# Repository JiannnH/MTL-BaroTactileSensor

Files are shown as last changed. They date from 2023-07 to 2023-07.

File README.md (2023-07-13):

# MTL-BaroTactileSensor

This repository contains the code and hardware design for the research project titled "Superresolution of a Barometric Tactile Sensor." The project is being conducted as part of an MSc Thesis at Imperial College London, which is continually updating.

# Project Description
The objective of this project is to develop an integrated tactile sensor solution based on traditional barometers to produce a more precise and sophisticated tactile output. The project encompasses the entire development cycle, including PCB design, hardware design, data collection, and deep learning model training.

The primary focus of the project is on enhancing the resolution of tactile sensors using machine learning techniques.

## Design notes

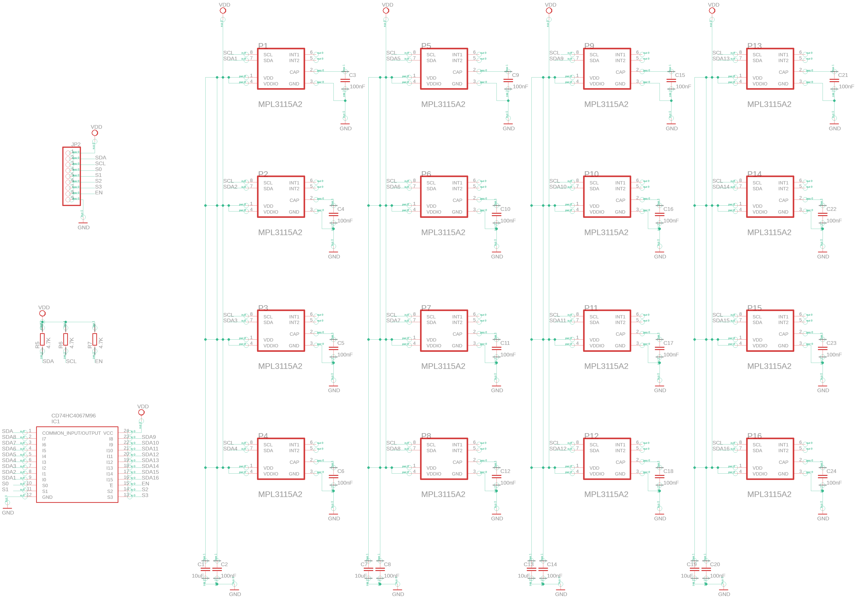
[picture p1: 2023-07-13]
PCB/BarometerMTL_V3.1/Schematic.png

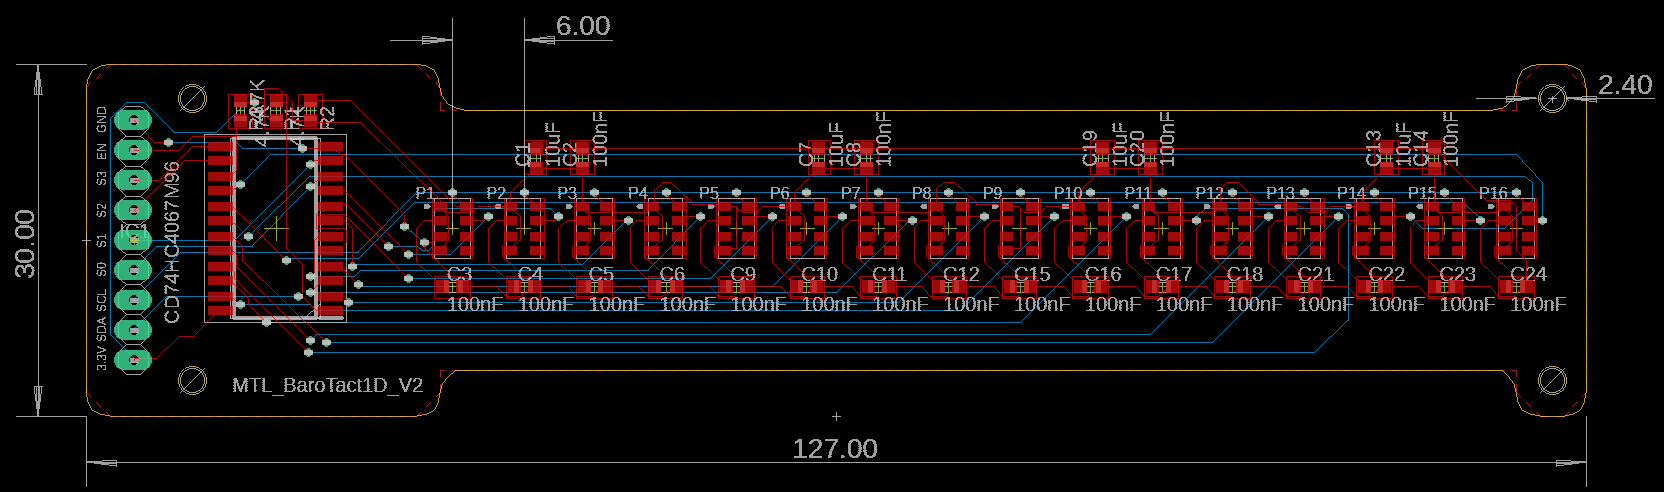
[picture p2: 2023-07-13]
PCB/MTL_BaroTact_V3(Manu_version)/1D_img.png

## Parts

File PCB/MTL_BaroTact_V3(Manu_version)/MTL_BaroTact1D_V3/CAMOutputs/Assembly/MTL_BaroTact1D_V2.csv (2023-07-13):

 |  |  | 1D
Qty | Name | Price(?) | Link | Min order Qty | Note
1 | PINHD-1X9 | 0.647 | https://uk.rs-online.com/web/p/pcb-headers/0453224 | 10 |  | 0.647
1 | CD74HC4067M96 | 0.855 | https://uk.rs-online.com/web/p/multiplexer-demultiplexer-ics/6622577 | 10 |  | 0.855
16 | MPL3115A2 | 8.54 | https://uk.rs-online.com/web/p/pressure-sensor-ics/7500841 | 1 | If ordering 490 pieces or more, the price is ?4.785 | 136.64
1 | 4.7K RR0603 | 0.022 | https://uk.rs-online.com/web/p/thermistor-ics/0110510 | 25 |  | 0.022
1 | 10uF CC0603 | 0.243 | https://uk.rs-online.com/web/p/mlccs-multilayer-ceramic-capacitors/8151377 | 25 |  | 0.243
1 | 100nF CC0603 | 0.243 | https://uk.rs-online.com/web/p/mlccs-multilayer-ceramic-capacitors/8151377 | 25 |  | 0.243
 | Est Price/set | 138.65
 |  |  | 2D
Qty | Name | Price(?) | Link | Min order Qty | Note
1 | PINHD-1X9 | 0.647 | https://uk.rs-online.com/web/p/pcb-headers/0453224 | 10 |  | 0.647
1 | CD74HC4067M96 | 0.855 | https://uk.rs-online.com/web/p/multiplexer-demultiplexer-ics/6622577 | 10 |  | 0.855
16 | MPL3115A2 | 8.54 | https://uk.rs-online.com/web/p/pressure-sensor-ics/7500841 | 1 | If ordering 490 pieces or more, the price is ?4.785 | 136.64
1 | 4.7K RR0603 | 0.022 | https://uk.rs-online.com/web/p/thermistor-ics/0110510 | 25 |  | 0.022
1 | 10uF CC0402 | 0.131 | https://uk.rs-online.com/web/p/mlccs-multilayer-ceramic-capacitors/8467271 | 25 |  | 0.131
1 | 100nF CC0402 | 0.041 | https://uk.rs-online.com/web/p/mlccs-multilayer-ceramic-capacitors/1034089 | 50 |  | 0.041
 | Est Price/set | 138.336

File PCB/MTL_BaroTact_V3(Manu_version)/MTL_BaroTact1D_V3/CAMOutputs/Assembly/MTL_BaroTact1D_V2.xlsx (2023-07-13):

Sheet: MTL_BaroTact1D_V2
Qty;"Value";"Device";"Package";"Parts";"Description";"CIIVA_IDS";"COMPONENT_LINK_1_DESCRIPTION";"COMPONENT_LINK_1_URL";"COMPONENT_LINK_3_DESCRIPTION";"COMPONENT_LINK_3_URL";"DATASHEET";"DATASHEET_VERSION";"DESCRIPTION";"FOOTPRINT_VARIANT_NAME_0";"FSCL20_PF";"FSCL400_PF";"HEIGHT";"IMPORTED";"IMPORTED_FROM";"IMPORT_TS";"MANUFACTURER_NAME";"MANUFACTURER_PART_NUMBER";"MF";"MOUNTING_TECHNOLOGY";"MOUSER_PART_NUMBER";"MOUSER_PRICE-STOCK";"MPN";"OPERATING_TEMPERATURE_RANGE";"PACKAGE_DESCRIPTION";"PACKAGE_VERSION";"PACKING";"PIN_0_0_7_INSIDE_EDGE";"POPULARITY";"PREFIX";"RELEASE_DATE";"ROHS";"SPICEMODEL";"SPICEPREFIX";"VAULT_GUID";"VAULT_REVISION";"VDD";"VDDIO";
1;"";"PINHD-1X9";"1X09";"JP2";"PIN HEADER";"";"";"";"";"";"";"";"";"";"";"";"";"";"";"";"";"";"";"";"";"";"";"";"";"";"";"";"13";"";"";"";"";"";"";"";"";"";
20;"100nF";"CC0603";"C0603";"C2 | C3 | C4 | C5 | C6 | C8 | C9 | C10 | C11 | C12 | C14 | C15 | C16 | C17 | C18 | C20 | C21 | C22 | C23 | C24";"CAPACITOR | European symbol";"";"";"";"";"";"";"";"";"";"";"";"";"";"";"";"";"";"";"";"";"";"";"";"";"";"";"";"";"";"";"";"NONE";"C";"";"";"";"";
4;"10uF";"CC0603";"C0603";"C1 | C7 | C13 | C19";"CAPACITOR | European symbol";"";"";"";"";"";"";"";"";"";"";"";"";"";"";"";"";"";"";"";"";"";"";"";"";"";"";"";"";"";"";"";"NONE";"C";"";"";"";"";
3;"4.7K";"RR0603";"R0603";"R1 | R2 | R3";"RESISTOR | European symbol";"";"";"";"";"";"";"";"";"";"";"";"";"";"";"";"";"";"";"";"";"";"";"";"";"";"";"";"";"";"";"";"NONE";"R";"";"";"";"";
1;"CD74HC4067M96";"CD74HC4067M96";"SOIC127P1030X265-24N";"IC1";"High Speed CMOS 16-Channel Analog Multiplexer/Demultiplexer";"";"";"";"";"";"";"";"High Speed CMOS 16-Channel Analog Multiplexer/Demultiplexer";"";"";"";"2.65mm";"";"";"";"Texas Instruments";"CD74HC4067M96";"";"";"595-CD74HC4067M96";"https://www.mouser.co.uk/ProductDetail/Texas-Instruments/CD74HC4067M96?qs=xFfolx0DHx0XT7d9xTTZBA%3D%3D";"";"";"";"";"";"";"";"";"";"";"";"";"";"";"";"";
16;"FREESCALE_SEMICONDUCTOR_MPL3115A2FREESCALE_SEMICONDUCTOR_MPL3115A2_0_0";"FREESCALE_SEMICONDUCTOR_MPL3115A2FREESCALE_SEMICONDUCTOR_MPL3115A2_0_0";"FREESCALE_SEMICONDUCTOR_MPL3115A2_0";"P1 | P2 | P3 | P4 | P5 | P6 | P7 | P8 | P9 | P10 | P11 | P12 | P13 | P14 | P15 | P16";"FRES-MPL3115A2-8";"1172243";"Manufacturer URL";"http://www.freescale.com/";"Package Specification";"http://cache.freescale.com/files/shared/doc/package_info/98ASA00260D.pdf";"http://cache.freescale.com/files/sensors/doc/data_sheet/MPL3115A2.pdf";"Rev. 3.0";"";"Manufacturer Recommended";"4 MHz Max.";"400 KHz Max.";"";"yes";"vault";"1521845373";"";"";"Freescale Semiconductor";"Surface Mount";"";"";"MPL3115A2";"-40 to 85 degC";"8-Pin Land Grid Array | Body 5 x 3 mm | Pitch 1.25 mm";"Rev. O";"Tray";"clock";"";"U";"1435138815";"Yes";"";"";"C9CA789F-172F-4FBE-A7EA-5C936E43DE32";"13F1D4E8-B129-4F1C-B772-6A98733F3276";"1.95 to 3.6 V";"1.62 to 3.6 V";

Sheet: Sheet1
1D
Qty | Name | Price(£) | Link | Min order Qty | Note
1 | PINHD-1X9 | 0.647 | https://uk.rs-online.com/web/p/pcb-headers/0453224 | 10 |  | 0.647
1 | Nexperia HEF4067BT | 1.93 | https://uk.rs-online.com/web/p/multiplexer-demultiplexer-ics/0788817 | 1 |  | 1.93
1 | CD74HC4067M96 | 0.855 | https://uk.rs-online.com/web/p/multiplexer-demultiplexer-ics/6622577 | 10 | Currently out of stock | 0.855
16 | MPL3115A2 | 8.54 | https://uk.rs-online.com/web/p/pressure-sensor-ics/7500841 | 1 | If ordering 490 pieces or more, the price is £4.785 | 136.64
3 | 4.7K RR0603 | 0.022 | https://uk.rs-online.com/web/p/thermistor-ics/0110510 | 25 |  | 0.066 | 71-CRCW0603J-4.7K-E3
4 | 10uF CC0603 | 0.243 | https://uk.rs-online.com/web/p/mlccs-multilayer-ceramic-capacitors/8151377 | 25 |  | 0.972 | 581-0603ZW106MAT2A
20 | 100nF CC0603 | 0.243 | https://uk.rs-online.com/web/p/mlccs-multilayer-ceramic-capacitors/8151377 | 25 |  | 4.86 | 581-0603YC104J4T4A
 | Est Price/set | 145.115
2D
Qty | Name | Price(£) | Link | Min order Qty | Note
1 | PINHD-1X9 | 0.647 | https://uk.rs-online.com/web/p/pcb-headers/0453224 | 10 |  | 0.647
1 | Nexperia HEF4067BT | 1.93 | https://uk.rs-online.com/web/p/multiplexer-demultiplexer-ics/0788817 | 1 |  | 1.93
1 | CD74HC4067M96 | 0.855 | https://uk.rs-online.com/web/p/multiplexer-demultiplexer-ics/6622577 | 10 | Currently out of stock | 0.855
16 | MPL3115A2 | 8.54 | https://uk.rs-online.com/web/p/pressure-sensor-ics/7500841 | 1 | If ordering 490 pieces or more, the price is £4.785 | 136.64
3 | 4.7K RR0603 | 0.022 | https://uk.rs-online.com/web/p/thermistor-ics/0110510 | 25 |  | 0.066 | 71-CRCW0603J-4.7K-E3
4 | 10uF CC0402 | 0.131 | https://uk.rs-online.com/web/p/mlccs-multilayer-ceramic-capacitors/8467271 | 25 |  | 0.524 | 581-0402ZD106MAT2A
20 | 100nF CC0402 | 0.041 | https://uk.rs-online.com/web/p/mlccs-multilayer-ceramic-capacitors/1034089 | 50 |  | 0.82 | 581-04023C104KAT2A
 | Est Price/set | 140.627

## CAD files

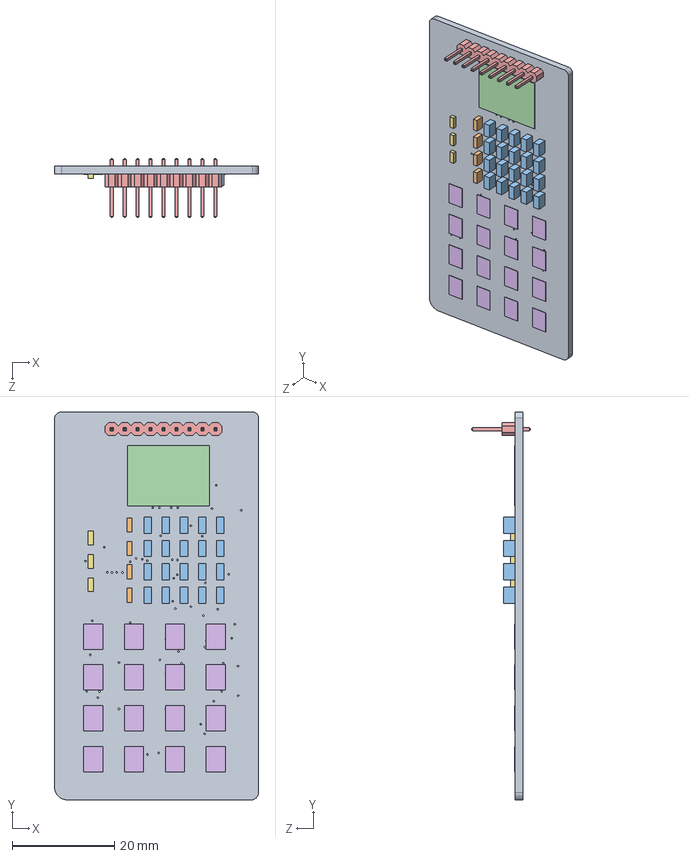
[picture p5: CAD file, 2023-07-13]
PCB/Baro_V3.SLDASM
40.0 x 76.0 x 11.5 mm
Board.step
10uF.step x 4
100nF.step x 20
CD74HC4067M96.step
1X09.step
FREESCALE_SEMICONDUCTOR_MPL3115A2FREESCALE_SEMICONDUCTOR_MPL3115A2_0_0.step x 16
4.7K.step x 3

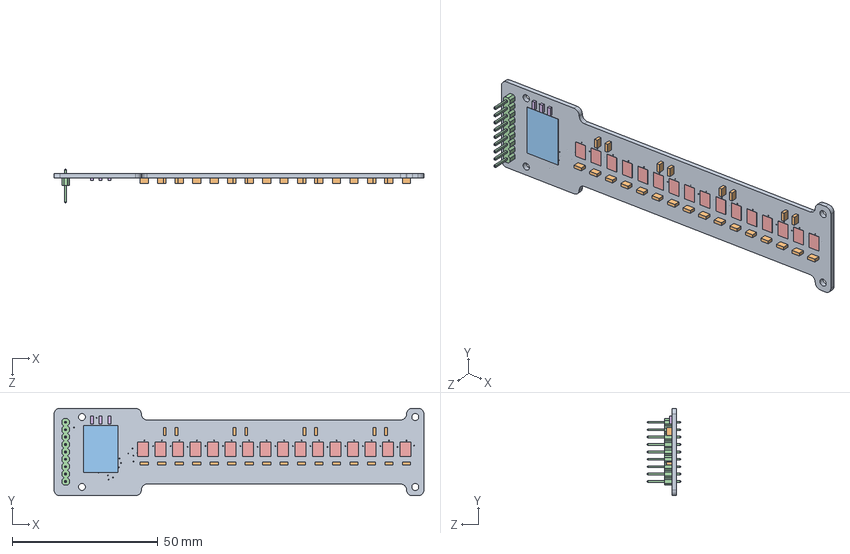
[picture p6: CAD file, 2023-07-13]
Mold/MTL_BaroTact1D_V3.SLDASM
127.0 x 30.0 x 11.5 mm
Board.step
100nF.step x 24
CD74HC4067M96.step
1X09.step
FREESCALE_SEMICONDUCTOR_MPL3115A2FREESCALE_SEMICONDUCTOR_MPL3115A2_0_0.step x 16
4.7K.step x 3

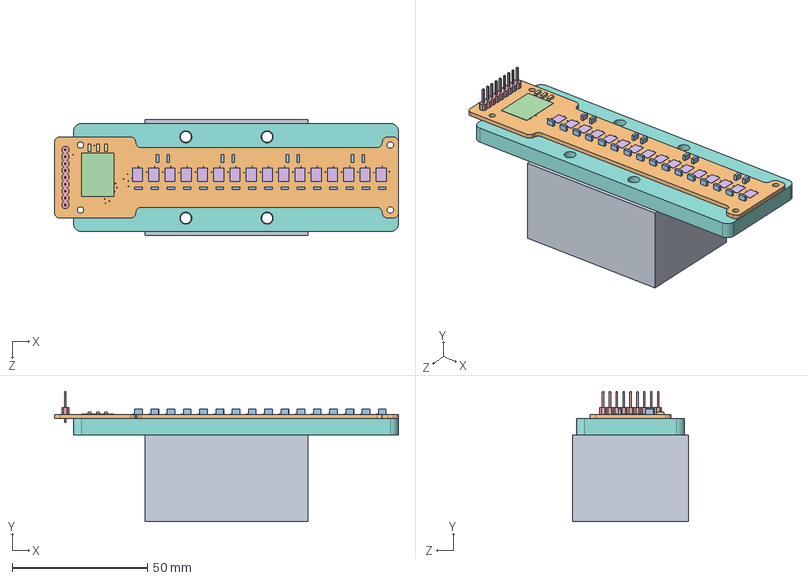
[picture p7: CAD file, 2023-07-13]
Mold/Assem1_rig.SLDASM
127.0 x 48.1 x 43.0 mm
Rig_base
Board.step
100nF.step x 24
CD74HC4067M96.step
1X09.step
FREESCALE_SEMICONDUCTOR_MPL3115A2FREESCALE_SEMICONDUCTOR_MPL3115A2_0_0.step x 16
4.7K.step x 3
Rig_bed

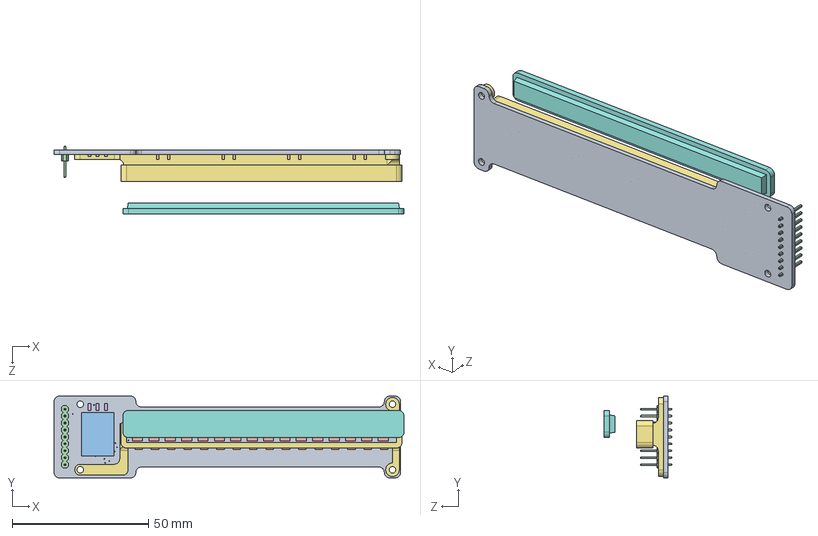
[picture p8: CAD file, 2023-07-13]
Mold/MTL_BaroTact1D_V3_Mold_ASM.SLDASM
128.2 x 30.0 x 24.8 mm
Board.step
100nF.step x 24
CD74HC4067M96.step
1X09.step
FREESCALE_SEMICONDUCTOR_MPL3115A2FREESCALE_SEMICONDUCTOR_MPL3115A2_0_0.step x 16
4.7K.step x 3
mould_b
mould_t

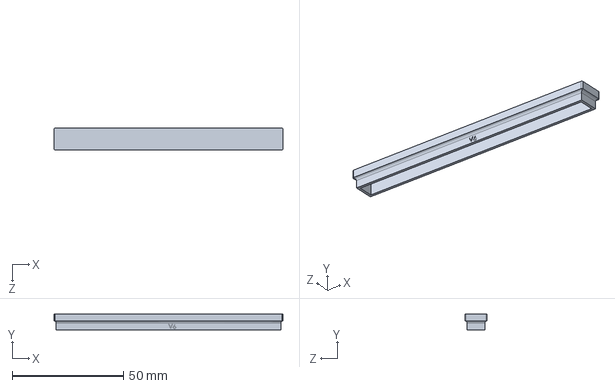
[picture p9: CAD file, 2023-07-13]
Mold/Mold_v6/mould_b_V6.SLDPRT
103.0 x 7.00 x 10.0 mm

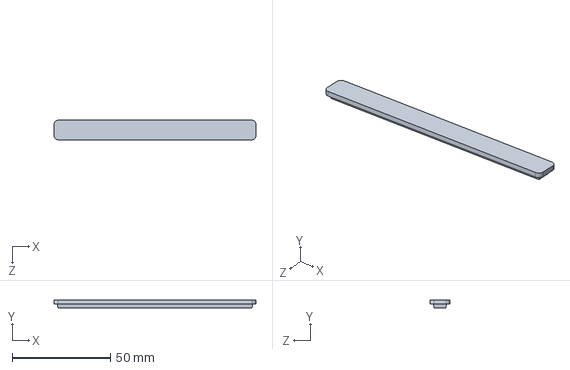
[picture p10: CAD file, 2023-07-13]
Mold/mould_t.SLDPRT
103.0 x 4.00 x 10.0 mm

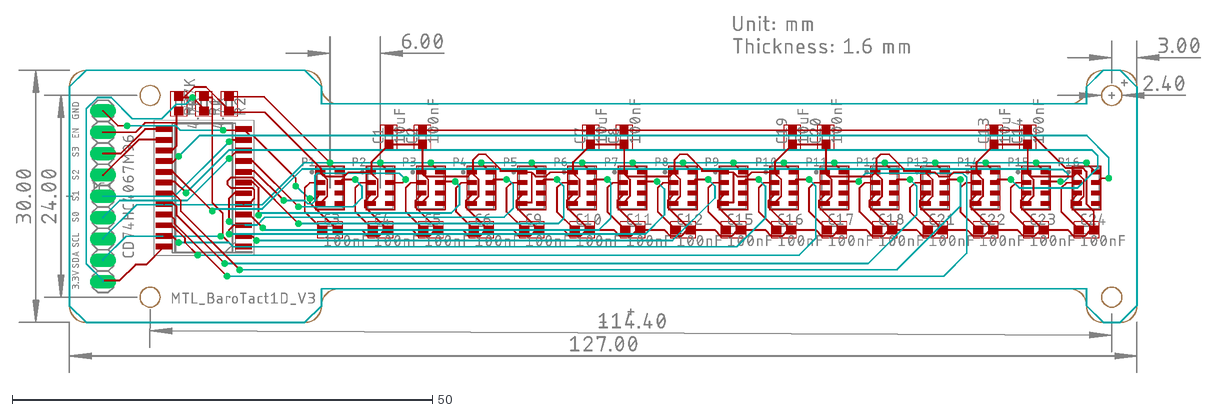
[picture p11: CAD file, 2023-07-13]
PCB/MTL_BaroTact_V3(Manu_version)/MTL_BaroTact1D_V3/MTL_BaroTact1D_V3.dxf
141.0 x 42.5

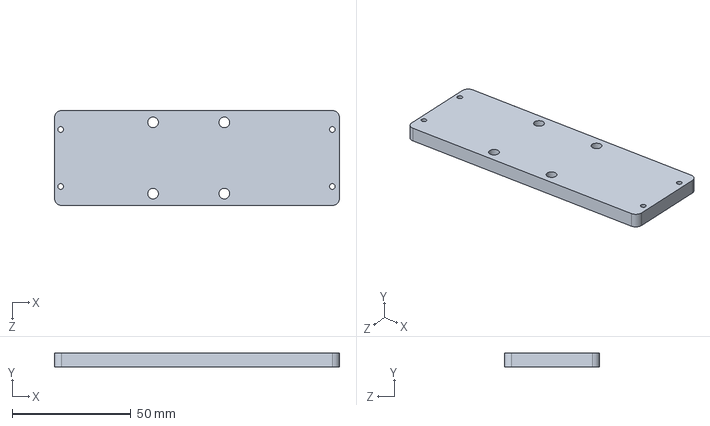
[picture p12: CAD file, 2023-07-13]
Mold/Rig_bed.SLDPRT
120.0 x 6.00 x 40.0 mm

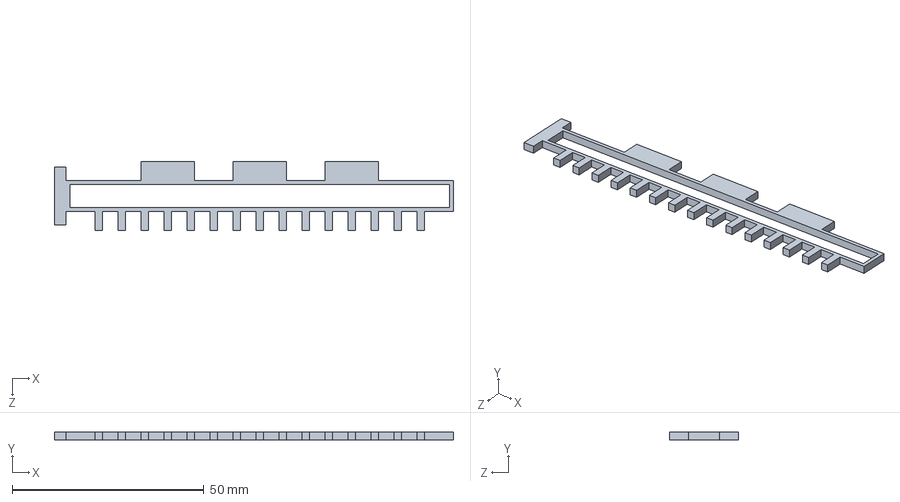
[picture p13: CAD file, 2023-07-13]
Mold/Mold_v6/frame.SLDPRT
104.0 x 2.00 x 18.0 mm

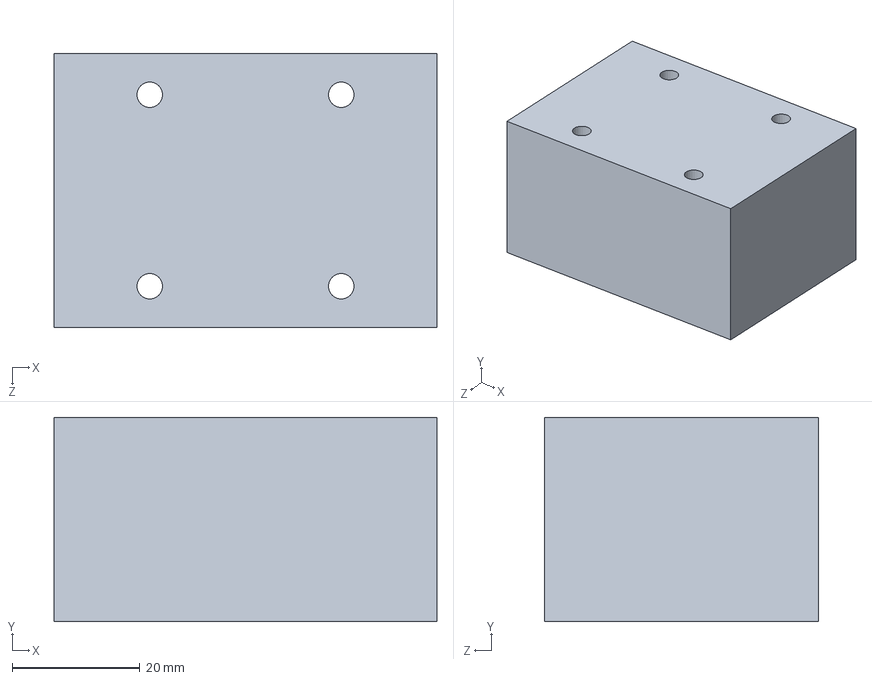
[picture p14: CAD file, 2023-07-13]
Mold/Rig_base.SLDPRT
60.0 x 32.0 x 43.0 mm

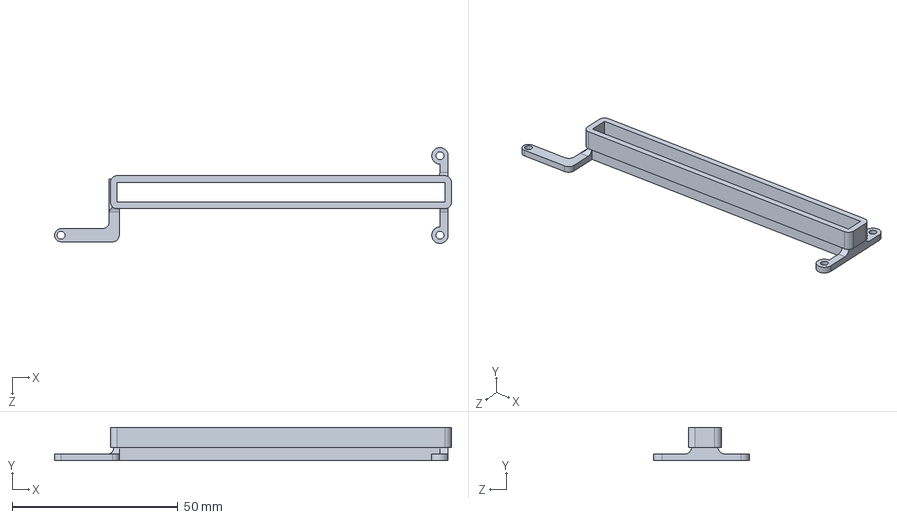
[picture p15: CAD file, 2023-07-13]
Mold/mould_b.SLDPRT
119.9 x 10.0 x 29.0 mm

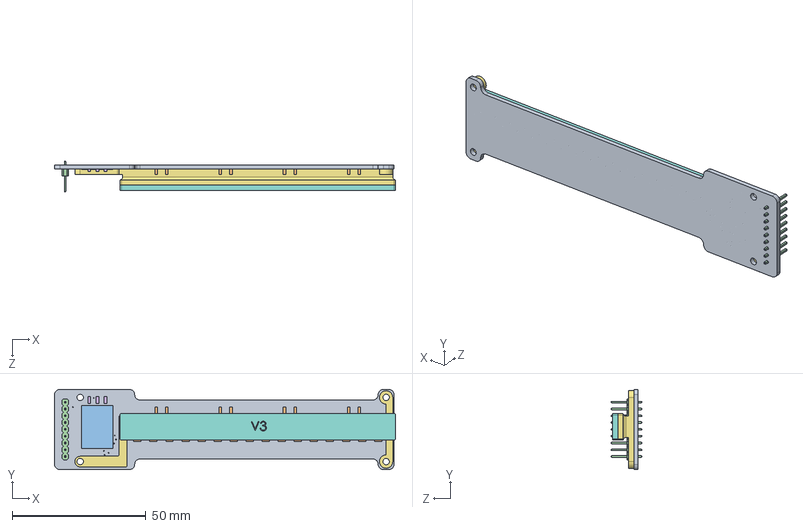
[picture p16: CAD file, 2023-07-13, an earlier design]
Mold/Mold_v5/MTL_BaroTact1D_V3.SLDASM
127.5 x 30.0 x 11.5 mm
Board.step
100nF.step x 24
CD74HC4067M96.step
1X09.step
FREESCALE_SEMICONDUCTOR_MPL3115A2FREESCALE_SEMICONDUCTOR_MPL3115A2_0_0.step x 16
4.7K.step x 3
mould_b_V3
mould_t_V3

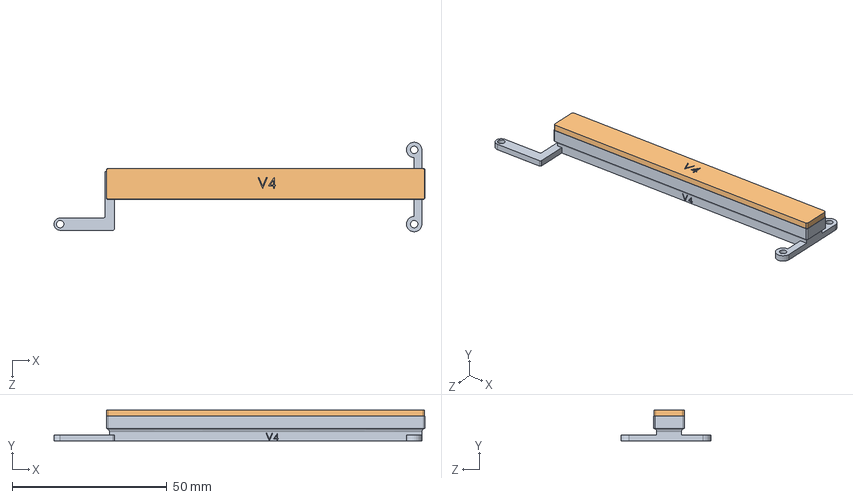
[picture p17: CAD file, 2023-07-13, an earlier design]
Mold/Mold_v4/MTL_BaroTact1D_V3_Mold_ASM_V4.SLDASM
119.9 x 10.0 x 29.0 mm
mould_b_V4
mould_t_V4

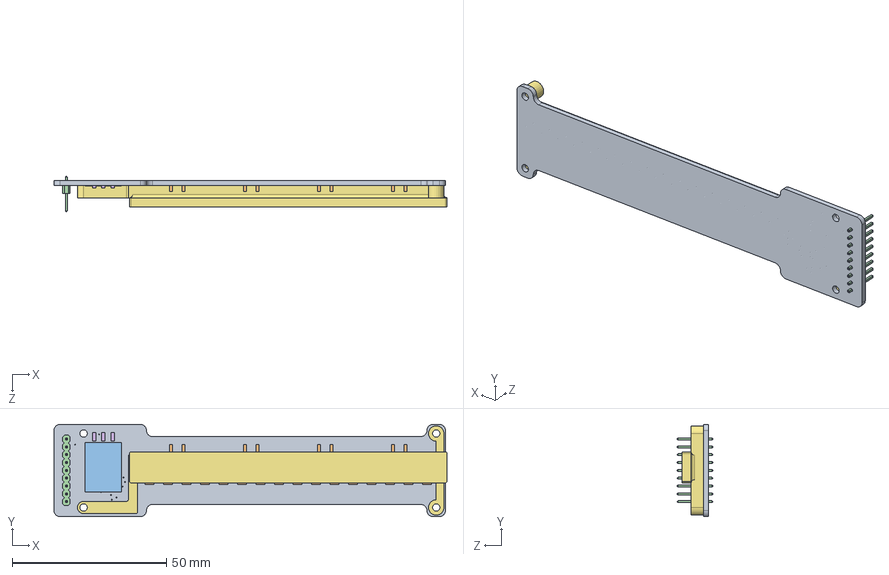
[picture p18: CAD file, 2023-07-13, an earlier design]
Mold/Mold_v5/Assem2.SLDASM
127.5 x 30.0 x 11.5 mm
Board.step
100nF.step x 24
CD74HC4067M96.step
1X09.step
FREESCALE_SEMICONDUCTOR_MPL3115A2FREESCALE_SEMICONDUCTOR_MPL3115A2_0_0.step x 16
4.7K.step x 3
mould_b_V5

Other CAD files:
Mold/Mold_v2/MTL_BaroTact1D_V3.SLDASM
Mold/Mold_v5/MTL_BaroTact1D_V3_Mold_ASM.SLDASM
Mold/Mold_v2/mould_b_V2.SLDPRT
Mold/Mold_v2/mould_t.SLDPRT
Mold/Mold_v3/MTL_BaroTact1D_V3_Mold_ASM.SLDASM
Mold/Mold_v3/mould_b_V3.SLDPRT
Mold/Mold_v3/mould_b_V3.STL
Mold/Mold_v3/mould_t.SLDPRT
Mold/Mold_v3/mould_t_V3.SLDPRT
Mold/Mold_v3/mould_t_V3.STL
Mold/Mold_v4/MTL_BaroTact1D_V3_Mold_ASM.SLDASM
Mold/Mold_v4/mould_b_V4.SLDPRT
Mold/Mold_v4/mould_b_V4.STL
Mold/Mold_v4/mould_t.SLDPRT
Mold/Mold_v4/mould_t_V4.SLDPRT
Mold/Mold_v4/mould_t_V4.STL
Mold/Mold_v5/mould_b_V5.SLDPRT
Mold/Mold_v5/mould_b_V5.STL
Mold/Mold_v6/frame.STL
Mold/Mold_v6/mould_b_V6.STL
Mold/Rig_bed.DXF
Mold/Rig_bed.SLDDRW
Mold/mould_b.STL
PCB/BarometerMTL_V3/BarometerMTL_V3/Parts/IC_Freescale%20Semiconductor_MPL3115A2/68ce6ad0f13c7c83f91c695a0baf98bd6f5786ad.step

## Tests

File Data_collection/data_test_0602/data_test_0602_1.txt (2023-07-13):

100650 

100652.00 100916.75 100529.75 100789.50 
100654.50 100917.50 100527.00 100789.50 
100648.50 100915.75 100528.00 100790.50 
100644.25 100912.75 100524.50 100794.50 
100642.50 100908.00 100514.50 100740.50 
100586.00 100875.25 100482.50 100721.50 
100581.75 100859.75 100486.75 100731.25 
100585.00 100861.50 100482.50 100725.75 
100576.50 100848.50 100476.50 100711.00 
100562.00 100838.75 100473.25 100709.50 
100562.25 100841.75 100478.00 100716.00 
100567.00 100843.00 100475.50 100699.75 
105041.00 100958.75 100329.50 100573.50 
126987.50 100630.75 100203.25 100508.00 
133708.50 100336.50 100146.25 100504.75 
133464.50 100295.25 100178.25 100541.00 
132274.00 100330.75 100173.25 100551.00 
133366.25 100364.50 100197.75 100568.50 
124433.00 100729.00 100486.75 100752.25 
101396.50 100901.50 100490.25 100754.00 
101058.25 100901.25 100487.00 100743.25 
100950.75 101167.50 100376.50 100660.00 
103931.00 111718.00 99671.75 100381.75 
105552.00 113443.25 99773.25 100462.75 
105197.25 112375.75 99723.25 100482.75 
104626.75 111839.00 99770.00 100552.75 
102531.50 102821.00 100452.50 100753.75 
101349.50 101950.25 100471.00 100752.25 
101194.00 101670.25 100489.25 100751.50 
101082.00 101483.00 100488.75 100746.75 
101008.25 101380.50 100494.50 100748.75 
100961.75 102185.25 100316.50 100439.25 
101066.50 122973.75 99990.25 100330.00 
101016.25 121895.25 100069.00 100386.25 
100829.00 118806.25 100089.25 100456.25 
100951.50 116785.00 100168.75 100540.00 
101230.00 106860.00 100550.50 100761.00 
101016.75 102045.75 100556.50 100764.25 
100967.00 101737.50 100556.50 100762.25 
100935.00 101587.00 101400.50 100361.25 
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

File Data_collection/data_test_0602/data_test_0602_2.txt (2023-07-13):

102.50 100567.75 

100449.50 100695.25 100250.50 100567.75 
100440.75 100683.25 100251.00 100570.00 
100431.25 100684.50 100252.50 100567.75 
100427.00 100674.50 100254.50 100569.50 
100423.50 100671.50 100255.25 100567.50 
100415.00 100663.50 100257.00 100573.25 
100416.50 100658.00 100257.25 100572.25 
100411.75 100654.75 100255.50 100569.50 
100377.50 100581.50 100151.00 100309.50 
100221.75 100510.50 100115.25 100288.00 
100206.75 100494.50 100116.00 100273.25 
101157.75 100649.00 100033.00 100078.75 
135274.75 100587.75 99727.50 100122.00 
141710.50 100422.50 99746.00 100163.00 
109380.00 100838.75 100311.50 100643.25 
101102.75 100768.25 100289.75 100594.50 
100820.75 100704.50 100258.25 100576.75 
102209.75 107312.25 99575.50 100167.25 
111736.00 116460.00 99165.50 100192.75 
109511.00 116268.75 99313.50 100340.00 
102730.00 102565.25 100201.50 100582.25 
101320.50 101695.75 100227.00 100579.00 
101070.50 103110.75 100701.00 100273.00 
100720.75 123186.25 101090.50 99847.75 
100430.50 137385.50 101186.00 100009.25 
100626.25 103042.00 100506.25 100569.75 
100828.00 101866.25 100421.50 100566.25 
100750.75 101559.50 101133.75 100285.75 
100451.00 108130.25 117291.50 99634.00 
100319.50 108842.25 108648.75 100488.75 
100668.00 101802.00 101322.25 100533.75 
100665.00 101491.25 100960.00 100567.50 
100631.25 101293.75 112772.75 101642.50 
100465.00 100756.75 129981.75 101487.00 
100480.25 100740.25 127326.25 101569.00 
100571.25 101148.25 102129.25 100722.50 
100542.75 101075.50 101421.50 100724.50 
100604.50 101066.25 101139.75 103025.00 
100543.50 100774.50 106100.50 112692.25 
100492.25 100593.75 107616.00 113358.25 
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

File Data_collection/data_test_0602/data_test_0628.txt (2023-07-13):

108424.00 92469.50 86373.25 113262.75 
108414.25 92462.75 86371.50 113268.00 
108418.25 92462.25 86373.50 113260.00 
108414.75 92464.50 86377.75 113277.75 
108419.00 92466.25 86370.75 113267.25 
108406.00 92469.50 86382.75 113263.75 
108416.25 92466.50 86377.50 113264.75 
108420.75 92468.25 86378.50 113267.25 
108419.50 92469.75 86380.00 113263.00 
108422.00 92462.00 86376.25 113270.50 
108413.25 92472.00 86381.50 113260.75 
108415.25 92455.25 86372.00 113268.25 
108424.50 92470.00 86381.00 113270.00 
108414.75 92464.75 86376.50 113266.50 
108417.50 92446.00 86377.75 113270.00 
108421.75 92465.00 86369.25 113264.00 
108420.00 92470.00 86376.00 113277.25 
108415.75 92459.50 86383.00 113273.50 
108416.00 92465.75 86373.50 113262.50 
108421.50 92469.75 86374.00 113267.00 
108415.00 92465.25 86375.00 113269.00 
108415.25 92468.25 86372.50 113270.75 
108428.25 92471.75 86381.50 113265.00 
108421.75 92463.00 86382.50 113263.25 
108423.25 92470.00 86371.00 113260.75 
108419.25 92458.50 86374.25 113263.25 
108424.50 92463.75 86384.50 113265.25 
108421.75 92463.75 86373.75 113267.00 
108415.00 92469.00 86373.50 113269.00 
108423.25 92470.25 86374.50 113265.75 
108412.50 92467.00 86376.50 113274.00 
108422.00 92474.25 86370.50 113277.00 
108414.50 92457.75 86371.25 113269.25 
108421.75 92469.25 86373.00 113277.00 
108415.50 92472.25 86379.75 113277.75 
108411.00 92462.50 86379.50 113271.50 
108416.75 92462.00 86374.25 113277.25 
108413.00 92468.00 86380.00 113277.00 
108412.75 92464.75 86378.50 113276.00 
108417.50 92456.75 86379.00 113275.00 
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

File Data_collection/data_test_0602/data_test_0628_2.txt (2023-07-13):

[2023-06-28 03:15:51.200]
RX£º110521.75 92743.50 86732.00 115037.75 50 86698.75 115042.75 
36.00 
110518.50 92726.00 86700.50 115046.25 
110520.50 92720.00 86699.50 115034.00 
110523.50 92714.00 86698.75 115042.75 
36.00 
110518.50 92726.00 86700.50 115046.25 
110520.50 92720.00 86699.50 115034.00 
110523.50 92714.00 86698.75 115042.75 
110521.75 92719.25 86696.75 115050.00 
110527.00 92715.50 86701.00 115034.25 
110533.50 92732.50 86692.50 115050.25 
110531.25 92717.75 86684.75 115042.50 
110521.50 92717.75 86692.00 115035.00 
110527.25 92719.00 86695.50 115040.75 
110524.75 92713.75 86687.25 115043.75 
110530.75 92716.00 86689.00 115042.75 
110530.25 92713.75 86691.25 115043.75 
110536.75 92715.00 86684.25 115044.25 
110540.00 92709.00 86689.00 115050.25 
110540.50 92712.75 86689.00 115044.50 
110531.25 92716.50 86684.00 115046.50 
110535.75 92713.50 86686.50 115049.50 
110539.00 92720.50 86689.25 115039.25 
110526.50 92718.50 86685.75 115047.50 
110537.25 92708.75 86685.25 115041.75 
110537.75 92709.25 86680.00 115050.50 
110537.00 92704.75 86683.50 115057.00 
110543.25 92713.00 86682.25 115051.75 
110544.00 92713.00 86686.00 115043.50 
110538.25 92715.50 86686.25 115048.75 
110542.75 92703.25 86685.75 115041.50 
110550.00 92706.75 86675.25 115051.00 
110556.50 92708.25 86677.00 115060.00 
110545.50 92706.00 86681.50 115050.75 
110547.50 92708.75 86679.00 115051.00 
110546.75 92721.25 86683.50 115050.75 
110544.75 92705.00 86675.75 115050.75 
110548.75 92706.75 86676.00 115059.25 
110563.50 92710.75 86671.75 115063.00 
110554.00 92708.25 86678.75 115059.75 
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

[2023-06-28 03:16:00.025]
RX£º125751.50 95633.00 88327.75 115105.75 
126528.00 95430.00 87956.50 115115.50 
126046.75 95592.00 88517.00 115203.00 
125795.00 95587.50 88291.00 115108.50 
126108.50 95517.25 88175.50 115118.25 
126174.25 95449.75 87985.25 115120.25 
126393.75 95258.75 87515.25 115127.75 
126349.75 94926.50 87265.50 115131.75 
126176.00 94931.75 87463.50 115131.50 
125948.00 95050.00 87528.00 115134.25 
126130.75 94885.75 87477.00 115109.50 
126317.00 94953.75 87289.25 115132.75 
125868.50 94143.50 86810.75 115152.25 
123784.25 94183.00 87088.50 115166.25 
119940.75 94011.25 86912.50 115147.25 
116543.00 93754.25 87061.00 115147.00 
113775.75 93396.75 86840.00 115120.25 
113677.50 93346.25 86744.00 115116.50 
112917.50 93325.50 86571.25 115107.00 
111491.50 93132.75 86690.00 115128.50 
112189.75 93434.75 86645.75 115134.25 
112054.00 93665.50 87083.50 115151.25 
114936.50 94037.75 86988.75 115117.25 
114202.75 93883.25 87077.50 115116.25 
115082.75 94213.00 87396.75 115092.75 
116304.50 94552.25 87916.00 115331.75 
119191.50 94988.75 87703.50 115086.00 
122534.50 94804.00 87088.25 115109.00 
124272.75 95643.75 88999.75 117046.25 
121526.50 95979.75 89323.00 116658.75 
122398.00 95810.00 88868.75 116048.00 
122416.50 95721.75 88646.25 115560.75 
123686.25 95704.75 88199.50 114919.00 
126397.75 95652.75 88459.25 115382.00 
125001.25 95758.75 88578.00 115209.25 
125937.00 95509.50 88007.25 115187.25 
125431.00 95801.00 88840.75 115711.25 
125587.75 95767.50 88388.50 115113.00 
126699.75 95710.00 88245.50 115159.50 
126840.50 95641.00 87854.50 115164.00 
127886.50 94897.25 87065.00 115165.00 
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

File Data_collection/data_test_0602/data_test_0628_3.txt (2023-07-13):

111161.25 9285 0 
06.00 
110864.50 92784.25 86703.25 115505.50 
110860.25 92788.75 86704.00 115503.75 
110867.00 92787.00 86709.25 115500.50 
06.00 
110864.50 92784.25 86703.25 115505.50 
110860.25 92788.75 86704.00 115503.75 
110867.00 92787.00 86709.25 115500.50 
110869.00 92784.75 86703.50 115499.75 
110860.00 92797.00 86706.50 115506.00 
110856.75 92786.00 86705.50 115505.50 
110862.25 92783.50 86706.50 115503.50 
110856.25 92796.50 86703.00 115500.25 
110867.75 92779.00 86705.50 115501.25 
110855.00 92783.00 86702.25 115499.75 
110853.25 92777.75 86707.00 115490.50 
110861.00 92789.00 86696.00 115495.50 
110853.25 92796.00 86704.75 115492.00 
110861.75 92785.75 86704.00 115505.75 
110859.75 92787.25 86701.00 115501.75 
110857.75 92788.50 86706.50 115501.50 
110863.00 92788.00 86704.75 115494.25 
110858.50 92787.25 86700.75 115500.75 
110856.00 92780.25 86702.50 115497.25 
110858.00 92787.25 86702.75 115498.25 
110857.50 92786.25 86702.75 115495.75 
110851.25 92790.25 86706.75 115500.00 
110853.00 92785.75 86704.75 115495.25 
110856.00 92790.00 86705.75 115493.00 
110859.75 92786.75 86705.75 115494.50 
110852.75 92779.50 86704.25 115501.50 
110853.75 92784.25 86706.25 115500.50 
110849.50 92786.50 86709.00 115477.50 
110848.25 92796.00 86702.75 115493.25 
110865.50 92787.25 86704.25 115481.50 
110854.25 92786.50 86699.25 115497.00 
110858.50 92784.00 86702.25 115488.00 
110849.25 92783.50 86700.00 115492.00 
110842.25 92786.75 86700.75 115484.75 
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

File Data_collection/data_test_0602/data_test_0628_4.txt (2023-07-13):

108427.00 92524.75 86482.00 113464.50 
108424.00 92530.50 86480.75 113473.50 
108421.50 92521.50 86484.75 113465.50 
108426.50 92524.75 86484.50 113469.00 
108424.00 92529.75 86484.25 113474.25 
108422.50 92526.25 86482.25 113478.00 
108426.75 92522.50 86482.75 113466.00 
108431.00 92530.25 86475.50 113467.50 
108428.75 92533.75 86481.25 113470.50 
108421.50 92537.75 86482.25 113474.00 
108422.75 92535.00 86490.25 113482.50 
108424.25 92539.50 86488.50 113476.75 
108425.75 92527.50 86475.50 113467.25 
108424.50 92527.00 86474.75 113479.50 
108416.25 92527.00 86478.00 113479.00 
108429.75 92530.00 86483.00 113464.00 
108421.75 92533.25 86486.25 113484.00 
108422.00 92533.25 86482.50 113476.75 
108434.00 92525.25 86480.00 113461.25 
108420.25 92529.25 86480.25 113472.50 
108430.25 92532.75 86480.00 113474.50 
108430.00 92530.00 86484.00 113470.00 
108418.25 92524.00 86480.50 113465.00 
108439.00 92524.75 86481.50 113471.25 
108423.00 92522.00 86480.75 113465.50 
108427.25 92536.75 86478.75 113471.50 
108423.50 92532.00 86480.25 113469.50 
108428.50 92524.00 86473.50 113477.25 
108425.00 92519.00 86479.50 113460.75 
108424.00 92515.00 86481.50 113478.50 
108429.50 92530.50 86481.00 113465.75 
108427.00 92529.75 86485.00 113466.50 
108433.50 92531.00 86490.50 113470.75 
108410.50 92524.50 86488.50 113469.50 
108419.00 92529.00 86482.75 113469.50 
108423.25 92525.50 86481.00 113461.50 
108418.00 92527.75 86483.25 113472.00 
108418.50 92524.00 86483.00 113462.75 
108428.25 92523.50 86475.50 113477.00 
108411.75 92522.25 86482.00 113457.50 
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

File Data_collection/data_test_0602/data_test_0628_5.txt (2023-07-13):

109565.75 92874.00 86651.25 114578.75821.25 92584.25 86512.75 113469.75 
108823.00 92590.25 86504.25 113466.75 
108822.25 92586.00 86505.50 113463.50 
85.00 
108821.25 92584.25 86512.75 113469.75 
108823.00 92590.25 86504.25 113466.75 
108822.25 92586.00 86505.50 113463.50 
108827.00 92589.50 86507.00 113470.75 
108822.25 92587.00 86512.00 113467.50 
108825.75 92589.50 86514.25 113469.25 
108821.50 92592.00 86511.00 113481.75 
108825.50 92586.75 86506.50 113463.75 
108828.00 92591.75 86510.75 113475.25 
108825.75 92580.75 86503.25 113462.25 
108828.25 92593.00 86506.25 113464.50 
108826.25 92585.75 86505.25 113466.50 
108819.25 92581.75 86505.75 113459.00 
108821.75 92593.50 86506.25 113460.75 
108823.25 92593.25 86508.75 113465.75 
108828.50 92596.50 86506.25 113471.50 
108824.75 92596.00 86507.50 113473.25 
108814.00 92591.00 86501.25 113465.50 
108823.00 92586.50 86508.00 113459.00 
108820.00 92590.50 86506.25 113457.00 
108827.25 92593.25 86504.75 113469.25 
108819.25 92584.00 86501.00 113457.75 
108816.00 92592.50 86505.25 113466.00 
108816.00 92578.75 86511.00 113449.50 
108824.75 92583.00 86503.00 113470.50 
108808.50 92599.75 86504.75 113461.75 
108817.00 92586.25 86514.50 113459.00 
108818.25 92589.00 86509.75 113461.25 
108818.25 92586.50 86501.50 113466.00 
108825.75 92580.50 86502.75 113459.75 
108823.75 92579.25 86499.75 113462.75 
108821.00 92593.25 86510.50 113455.50 
108821.25 92591.75 86509.25 113448.75 
108824.50 92579.00 86502.25 113450.25 
108814.75 92591.50 86508.75 113445.00 
108810.00 92579.50 86509.00 113456.75 
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

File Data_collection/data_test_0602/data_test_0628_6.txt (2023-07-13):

110187.50 92976.25 86665.25 114100.50 
0.50 
83.25 
109001.75 92571.50 86575.00 113703.50 
109005.50 92578.00 86584.50 113684.00 
108993.00 92569.50 86572.75 113687.50 
83.25 
109001.75 92571.50 86575.00 113703.50 
109005.50 92578.00 86584.50 113684.00 
108993.00 92569.50 86572.75 113687.50 
83.25 
109001.75 92571.50 86575.00 113703.50 
109005.50 92578.00 86584.50 113684.00 
108993.00 92569.50 86572.75 113687.50 
109015.25 92564.50 86575.00 113695.25 
109003.75 92574.25 86579.50 113697.00 
109002.00 92568.75 86576.00 113690.50 
109000.50 92568.50 86569.00 113701.50 
109003.50 92572.75 86573.25 113694.25 
109003.50 92570.25 86573.25 113691.00 
109004.00 92568.25 86569.50 113691.75 
109004.25 92566.00 86573.75 113698.25 
109003.25 92579.25 86571.75 113692.00 
109008.50 92567.25 86562.75 113697.25 
109004.00 92577.00 86577.50 113686.00 
109006.25 92564.50 86578.75 113685.50 
108999.75 92569.50 86575.75 113682.50 
109011.00 92566.25 86576.25 113685.75 
109005.00 92568.00 86580.00 113698.00 
108996.75 92577.00 86564.75 113686.50 
109001.25 92563.25 86569.00 113690.25 
108993.50 92573.00 86579.50 113695.50 
108994.25 92573.75 86569.25 113692.50 
109005.75 92570.50 86565.00 113684.00 
108999.75 92568.00 86578.25 113690.00 
109005.75 92565.25 86569.00 113686.50 
109001.50 92576.25 86584.25 113688.75 
109007.75 92574.00 86571.75 113689.25 
109001.00 92568.50 86575.00 113699.25 
108999.25 92574.00 86573.00 113689.00 
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

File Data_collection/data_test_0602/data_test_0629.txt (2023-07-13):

110257.50 92962.00 88660.50 111955.50 
8.75 
110171.25 92959.75 88655.75 112020.50 
25.50 
110173.50 92966.75 88653.00 112025.00 
110178.75 92962.75 88660.75 112018.75 
110171.25 92959.75 88655.75 112020.50 
25.50 
110173.50 92966.75 88653.00 112025.00 
110178.75 92962.75 88660.75 112018.75 
110171.25 92959.75 88655.75 112020.50 
110179.75 92958.50 88656.50 112017.00 
110174.75 92946.75 88657.25 112021.75 
110175.00 92955.25 88652.25 112018.00 
110180.00 92952.50 88654.50 112016.25 
110173.50 92955.25 88656.50 112016.25 
110167.00 92959.00 88658.50 112020.25 
110174.75 92963.75 88657.25 112022.50 
110185.00 92959.50 88651.50 112016.00 
110173.50 92955.00 88666.25 112010.00 
110170.00 92962.75 88653.50 112021.25 
110167.50 92956.00 88658.00 112025.25 
110164.25 92958.75 88654.25 112016.00 
110179.75 92957.75 88652.25 112032.25 
110163.00 92955.00 88654.25 112014.75 
110174.75 92953.75 88653.25 112016.25 
110182.00 92952.50 88650.00 112014.50 
110174.75 92955.50 88651.75 112017.00 
110171.00 92957.75 88655.00 112014.00 
110171.25 92954.25 88653.75 112014.00 
110176.25 92955.75 88656.50 112019.50 
110169.00 92960.75 88659.25 112017.25 
110172.75 92960.75 88654.00 112016.75 
110167.00 92951.00 88661.00 112020.75 
110170.75 92950.75 88655.25 112016.50 
110182.00 92964.50 88657.00 112018.50 
110168.75 92952.25 88656.75 112017.75 
110175.25 92963.50 88652.50 112019.00 
110179.75 92958.25 88662.50 112028.75 
110168.00 92950.75 88654.00 112022.25 
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

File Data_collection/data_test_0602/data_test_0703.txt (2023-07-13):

96608.50 99987.75 97830.75 . 111684.25 
11677.50 
96606.75 99981.50 97840.75 111675.50 
96613.50 99974.75 97832.25 111665.75 
96611.75 99978.25 97842.00 111684.25 
11677.50 
96606.75 99981.50 97840.75 111675.50 
96613.50 99974.75 97832.25 111665.75 
96611.75 99978.25 97842.00 111684.25 
96614.75 99977.75 97840.25 111677.00 
96625.75 99983.75 97839.75 111673.50 
96610.75 99966.50 97841.25 111674.00 
96616.25 99978.00 97832.50 111672.25 
96613.75 99981.25 97839.00 111673.25 
96608.25 99971.75 97828.00 111669.50 
96615.50 99972.25 97841.25 111666.75 
96615.00 99980.00 97840.75 111676.50 
96617.25 99979.75 97840.75 111675.75 
96623.75 99987.50 97836.50 111678.25 
96616.00 99977.50 97845.50 111675.50 
96622.25 99983.50 97847.00 111673.75 
96612.00 99973.00 97844.25 111671.75 
96617.75 99986.25 97840.50 111665.50 
96614.25 99983.50 97834.75 111675.25 
96617.75 99976.25 97845.00 111681.00 
96606.00 99979.50 97839.75 111669.75 
96621.50 99977.75 97840.00 111675.25 
96610.25 99975.50 97838.75 111664.75 
96618.50 99982.00 97838.25 111680.75 
96619.50 99980.25 97841.25 111678.00 
96618.00 99982.00 97839.50 111673.50 
96617.25 99980.75 97834.50 111675.00 
96603.75 99976.25 97845.50 111668.00 
96618.25 99981.75 97839.50 111665.50 
96620.75 99978.75 97838.25 111669.75 
96613.00 99972.25 97847.75 111683.00 
96613.75 99978.50 97842.50 111683.50 
96620.00 99979.25 97839.75 111672.75 
96615.75 99976.75 97837.75 111684.00 
96617.75 99970.00 97841.25 111675.25 
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

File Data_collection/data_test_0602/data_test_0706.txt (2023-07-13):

101203.50 104207101578.00 113966.75 

101268.50 104256.75 101573.50 113969.75 
101268.00 104257.75 101570.75 113962.50 
101257.00 104258.25 101578.00 113966.75 

101268.50 104256.75 101573.50 113969.75 
101268.00 104257.75 101570.75 113962.50 
101257.00 104258.25 101578.00 113966.75 
101258.25 104261.25 101580.25 113955.50 
101274.25 104261.75 101578.50 113962.25 
101253.25 104261.00 101583.00 113969.00 
101264.75 104252.00 101576.50 113964.75 
101262.00 104257.50 101574.25 113960.25 
101270.00 104257.75 101582.25 113965.25 
101262.50 104259.50 101571.25 113955.25 
101267.25 104269.00 101571.00 113958.25 
101274.00 104258.75 101582.25 113961.25 
101269.75 104261.00 101581.50 113967.25 
101259.25 104256.00 101570.00 113967.00 
101268.00 104257.50 101581.00 113967.25 
101265.00 104261.25 101574.25 113961.00 
101263.00 104255.00 101570.75 113967.00 
101267.75 104265.00 101574.75 113959.75 
101266.75 104264.75 101575.75 113965.00 
101258.00 104254.25 101567.75 113962.50 
101266.00 104262.25 101578.75 113957.50 
101262.00 104255.50 101570.00 113967.75 
101270.75 104257.00 101572.50 113958.00 
101264.50 104257.50 101584.00 113954.00 
101266.75 104262.75 101574.00 113961.25 
101269.75 104253.75 101569.00 113955.25 
101265.75 104264.25 101572.25 113962.25 
101271.50 104263.50 101576.50 113958.00 
101261.75 104256.50 101574.50 113952.00 
101264.75 104264.75 101583.00 113954.00 
101279.50 104254.50 101580.50 113956.75 
101269.00 104254.00 101569.25 113955.00 
101269.75 104257.00 101576.75 113955.25 
101280.25 104261.00 101572.25 113965.50 
101264.75 104265.25 101589.50 113961.25 
101265.00 104258.00 101576.50 113963.00 
101269.25 104264.00 101575.25 113959.00 
101266.00 104253.75 101586.25 113962.25 
101268.50 104258.50 101576.00 113955.25 
101269.25 104256.50 101587.50 113968.75 
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

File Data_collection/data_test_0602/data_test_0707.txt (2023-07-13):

98171.25 102012.25 99905.25 110968.50 
98173.50 102007.00 99913.00 110970.75 
98174.75 102008.00 99902.25 110974.50 
98164.25 102010.75 99907.25 110970.25 
98168.75 102006.00 99904.00 110965.00 
98173.75 102002.75 99904.00 110965.75 
98166.50 102011.75 99904.50 110984.75 
98179.00 101997.00 99913.25 110972.25 
98175.00 102007.75 99905.50 110973.25 
98170.00 101997.25 99906.00 110966.00 
98177.75 102006.50 99906.75 110961.50 
98170.75 102010.75 99909.25 110979.00 
98176.75 102003.50 99906.00 110968.00 
98167.00 102003.00 99905.50 110967.25 
98183.50 101998.00 99908.25 110964.50 
98173.00 102003.00 99902.25 110966.75 
98179.25 102005.50 99908.00 110974.25 
98172.50 102006.25 99897.75 110982.50 
98180.50 102007.75 99910.00 110967.25 
98169.75 102008.50 99912.00 110976.25 
98170.00 102008.00 99911.50 110973.75 
98178.50 102003.25 99911.50 110970.00 
98179.50 102004.50 99916.75 110969.50 
98179.75 102006.50 99910.00 110983.00 
98176.25 102011.75 99911.25 110977.25 
98180.50 102003.75 99911.75 110973.25 
98193.75 101999.75 99911.50 110969.25 
98187.25 102009.50 99910.50 110966.50 
98191.75 102002.50 99915.50 110973.00 
98182.00 102008.50 99915.00 110959.50 
98174.75 102013.25 99910.00 110970.50 
98186.00 102007.00 99909.25 110969.00 
98182.50 102014.00 99914.00 110962.00 
98180.25 102004.75 99918.00 110979.00 
98177.75 102014.25 99909.25 110973.50 
98191.25 101998.50 99910.00 110968.00 
98180.75 101997.75 99908.25 110975.75 
98184.75 102012.50 99913.50 110975.00 
98193.00 102012.00 99913.75 110973.25 
98179.75 102010.25 99911.25 110969.75 
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

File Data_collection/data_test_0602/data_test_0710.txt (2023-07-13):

101337.50 101351.00 101330.00 101375 
101339.00 101339.00 101331.50 101387.75 

101338.00 101332.50 101328.75 101392.00 
101329.50 101335.00 101336.75 101380.75 
101339.00 101339.00 101331.50 101387.75 
101337.00 101337.75 101334.50 101387.75 
101334.75 101337.25 101342.00 101380.75 
101335.50 101336.75 101332.75 101384.50 
101339.00 101336.75 101334.50 101388.25 
101341.00 101339.00 101343.75 101370.50 
101341.00 101342.00 101334.50 101391.50 
101327.50 101331.50 101332.50 101385.50 
101343.75 101331.50 101339.00 101386.50 
101341.00 101335.75 101340.50 101384.50 
101338.25 101330.50 101338.50 101383.50 
101330.50 101339.00 101331.25 101380.50 
101342.00 101334.25 101342.25 101383.50 
101342.25 101341.00 101342.25 101385.50 
101336.50 101333.50 101332.25 101383.75 
101328.75 101336.75 101336.75 101387.00 
101340.50 101329.50 101339.25 101374.00 
101344.50 101346.00 101327.50 101384.75 
101344.50 101332.50 101335.50 101379.50 
101342.50 101331.50 101340.00 101383.25 
101336.25 101337.75 101328.75 101369.50 
101338.75 101334.75 101331.50 101385.00 
101344.00 101336.25 101324.25 101381.50 
101334.00 101338.75 101343.25 101380.25 
101345.25 101339.00 101339.00 101388.25 
101348.00 101341.00 101324.50 101379.75 
101336.00 101340.25 101338.50 101386.00 
101329.50 101338.25 101332.50 101374.25 
101343.75 101338.50 101336.50 101385.50 
101347.00 101338.25 101342.00 101396.50 
101326.50 101335.00 101331.00 101372.50 
101341.25 101342.75 101334.25 101373.75 
101339.50 101337.75 101335.25 101378.00 
101329.00 101338.00 101330.50 101392.00 
101340.00 101339.00 101338.50 101395.00 
101334.50 101333.00 101338.50 101381.25 
101339.00 101340.00 101338.75 101388.00 
101349.75 101335.50 101343.75 101381.75 
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

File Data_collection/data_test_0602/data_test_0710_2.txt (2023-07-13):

101345.75 101352.00 101351.00 10093.25 

101357.25 101352.25 101357.50 101399.25 
101365.00 101346.50 101361.00 101386.00 
101357.25 101342.00 101360.00 101393.25 
101360.25 101350.50 101370.00 101397.25 
101357.25 101349.50 101363.25 101401.75 
101349.75 101345.50 101357.75 101393.75 
101356.00 101352.25 101367.75 101395.50 
101358.25 101343.25 101361.50 101402.75 
101364.50 101346.50 101359.25 101395.75 
101347.75 101352.25 101354.50 101407.25 
101354.75 101356.50 101369.25 101402.50 
101359.50 101351.75 101365.75 101392.25 
101365.00 101351.25 101371.00 101386.25 
101360.75 101349.00 101359.75 101385.25 
101362.25 101349.00 101363.25 101392.75 
101362.50 101339.25 101356.75 101384.75 
101347.75 101348.50 101373.75 101397.25 
101362.50 101357.00 101361.25 101389.50 
101351.00 101348.00 101355.25 101403.75 
101355.25 101348.50 101369.50 101400.00 
101361.25 101350.75 101371.00 101403.00 
101351.50 101347.00 101358.75 101397.00 
101354.25 101346.00 101364.00 101394.50 
101357.75 101349.25 101362.25 101395.00 
101357.50 101339.50 101361.00 101396.00 
101360.50 101351.00 101350.00 101392.00 
101352.50 101345.75 101354.25 101399.00 
101363.00 101355.25 101369.50 101400.00 
101351.50 101347.75 101357.25 101408.75 
101365.00 101350.50 101358.50 101409.00 
101362.25 101352.50 101361.50 101393.00 
101368.00 101347.00 101366.25 101391.75 
101358.25 101350.00 101363.50 101399.75 
101361.00 101360.25 101359.50 101409.25 
101354.75 101343.75 101362.50 101399.25 
101362.25 101360.00 101365.75 101395.00 
101348.50 101345.75 101359.50 101406.00 
101356.00 101343.75 101358.50 101406.50 
101360.75 101348.00 101366.25 101397.50 
101364.50 101358.50 101366.25 101394.50 
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

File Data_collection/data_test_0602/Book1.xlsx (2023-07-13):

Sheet: Sheet1
Sensor 0 | Sensor 1 | Sensor 2 | Sensor 3
100652.00 | 100916.75 | 100529.75 | 100789.50
100654.50 | 100917.50 | 100527.00 | 100789.50
100648.50 | 100915.75 | 100528.00 | 100790.50
100644.25 | 100912.75 | 100524.50 | 100794.50
100642.50 | 100908.00 | 100514.50 | 100740.50
100586.00 | 100875.25 | 100482.50 | 100721.50
100581.75 | 100859.75 | 100486.75 | 100731.25
100585.00 | 100861.50 | 100482.50 | 100725.75
100576.50 | 100848.50 | 100476.50 | 100711.00
100562.00 | 100838.75 | 100473.25 | 100709.50
100562.25 | 100841.75 | 100478.00 | 100716.00
100567.00 | 100843.00 | 100475.50 | 100699.75
105041.00 | 100958.75 | 100329.50 | 100573.50
126987.50 | 100630.75 | 100203.25 | 100508.00
133708.50 | 100336.50 | 100146.25 | 100504.75
133464.50 | 100295.25 | 100178.25 | 100541.00
132274.00 | 100330.75 | 100173.25 | 100551.00
133366.25 | 100364.50 | 100197.75 | 100568.50
124433.00 | 100729.00 | 100486.75 | 100752.25
101396.50 | 100901.50 | 100490.25 | 100754.00
101058.25 | 100901.25 | 100487.00 | 100743.25
100950.75 | 101167.50 | 100376.50 | 100660.00
103931.00 | 111718.00 | 99671.75 | 100381.75
105552.00 | 113443.25 | 99773.25 | 100462.75
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

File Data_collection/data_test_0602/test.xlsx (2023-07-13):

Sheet: Sheet1
time(s) | T = 1 ms | T = 3 ms | T = 10 ms |  |  | 101939
0.08 | 92469.5 | 92587.5 | 92571.5 | 97832.25 |  | 102200
0.12 | 92462.75 | 92586 | 92562 | 97842 |  | 101724
0.16 | 92462.25 | 92583.5 | 92568.5 | 97840.25
0.2 | 92464.5 | 92578 | 92565 | 97839.75 | range | T = 1 ms | 2820.25
0.24 | 92466.25 | 92576.25 | 92569 | 97841.25 |  | T = 3 ms | 2164
0.28 | 92469.5 | 92584.75 | 92561 | 97832.5 |  | T = 10 ms | 1548
0.32 | 92466.5 | 92581.25 | 92563.25 | 97839
0.36 | 92468.25 | 92584.5 | 92571 | 97828
0.4 | 92469.75 | 92587 | 92569.75 | 97841.25
0.44 | 92462 | 92587.75 | 92560.75 | 97840.75
0.48 | 92472 | 92574.25 | 92562.75 | 97840.75
0.52 | 92455.25 | 92578 | 92561.5 | 97836.5
0.56 | 92470 | 92575.75 | 92568.5 | 97845.5
0.6 | 92464.75 | 92578 | 92568.5 | 97847
0.64 | 92446 | 92579.5 | 92564.5 | 97844.25
0.68 | 92465 | 92583.25 | 92557 | 97840.5
0.72 | 92470 | 92583.5 | 92565.5 | 97834.75
0.76 | 92459.5 | 92579.5 | 92561.25 | 97845
0.8 | 92465.75 | 92576.5 | 92559.5 | 97839.75
0.84 | 92469.75 | 92579 | 92564.75 | 97840
0.88 | 92465.25 | 92584.75 | 92564.75 | 97838.75
0.92 | 92468.25 | 92589.5 | 92568 | 97838.25
0.96 | 92471.75 | 92576.75 | 92573.25 | 97841.25
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

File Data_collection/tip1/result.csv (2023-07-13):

Sensor_1 | Sensor_2 | Sensor_3 | x | x_pred
-0.336145254107275 | -0.558555147635364 | -0.3713880627183218 | 0 | 0
-0.3368506823245146 | -0.5627059930664937 | -0.3727769033900069 | 0 | 0
-0.34166419251273744 | -0.5601943350030713 | -0.370473460324773 | 0 | 0
-0.33784658098414694 | -0.5605380355801712 | -0.3722687909491465 | 0 | 0
-0.33863500075635583 | -0.5630496936435937 | -0.3729462742036271 | 0 | 0
-0.3366432034370912 | -0.5598241959200406 | -0.3764014388014779 | 0 | 0
-0.3397553867484422 | -0.5584758321175717 | -0.37501259812979276 | 0 | 0
-0.3342364483429798 | -0.5623622924893938 | -0.3736237574581076 | 0 | 0
-0.3390499585312026 | -0.5600621424734175 | -0.37545296224520514 | 0 | 0
-0.3363942287721831 | -0.5593483028132868 | -0.3718623009964582 | 0 | 0
-0.3372656400993614 | -0.5638692873274472 | -0.370473460324773 | 0 | 0
-0.33826153875899373 | -0.5611196827106479 | -0.3722349167864225 | 0 | 0
-0.3395894036385035 | -0.5603794045445866 | -0.3719300493219062 | 0 | 0
-0.3400873529683196 | -0.5590839177539793 | -0.37314951917997125 | 0 | 0
-0.34116624318292127 | -0.5617277683470555 | -0.37382700243445177 | 0 | 0
-0.336145254107275 | -0.5619921534063631 | -0.3732850158308674 | 0 | 0
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

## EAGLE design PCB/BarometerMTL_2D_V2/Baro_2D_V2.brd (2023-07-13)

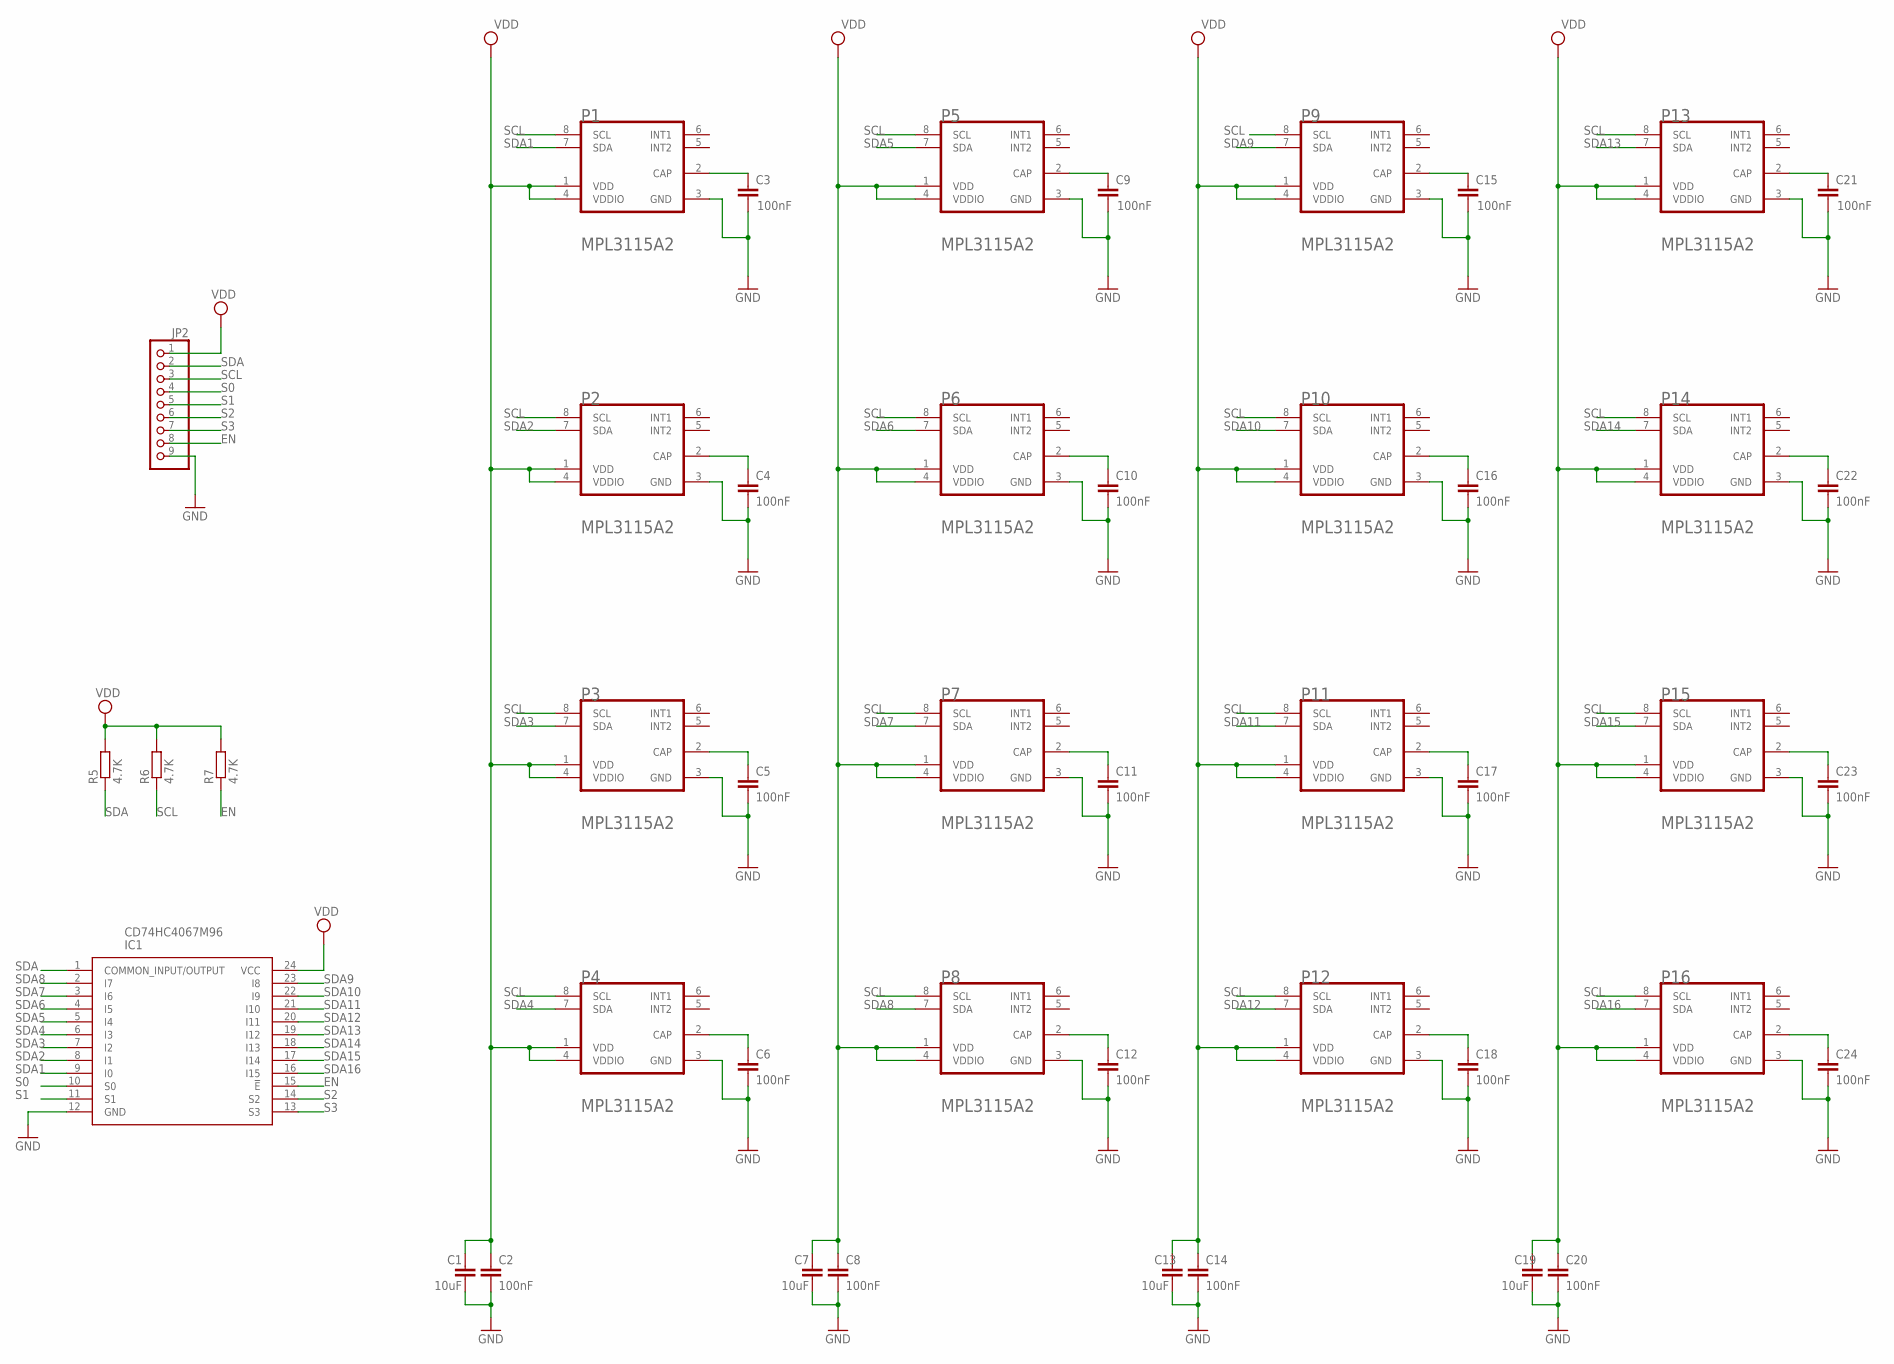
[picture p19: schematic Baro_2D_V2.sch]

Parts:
C1, C7, C13, C19: 10uF; C0402
C2, C3, C4, C5, C6, C8, C9, C10, C11, C12, C14, C15, C16, C17, C18, C20, C21, C22, C23, C24: 100nF; C0402
IC1: CD74HC4067M96; SOIC127P1030X265-24N
JP2: PINHD-1X9; 1X09
P1, P2, P3, P4, P5, P6, P7, P8, P9, P10, P11, P12, P13, P14, P15, P16: FREESCALE_SEMICONDUCTOR_MPL3115A2FREESCALE_SEMICO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; FREESCALE_SEMICONDUCTOR_MPL3115A2_0
R5, R6, R7: 4.7K; R0603

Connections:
EN: IC1.15 (!E), JP2.8, R7.1
GND: C1.2, C2.2, C3.2, C4.2, C5.2, C6.2, C7.2, C8.2, C9.2, C10.2, C11.2, C12.2, C13.2, C14.2, C15.2, C16.2, C17.2, C18.2, C19.2, C20.2, C21.2, C22.2, C23.2, C24.2, IC1.12 (GND), JP2.9, P1.3 (GND), P2.3 (GND), P3.3 (GND), P4.3 (GND), P5.3 (GND), P6.3 (GND), P7.3 (GND), P8.3 (GND), P9.3 (GND), P10.3 (GND), P11.3 (GND), P12.3 (GND), P13.3 (GND), P14.3 (GND), P15.3 (GND), P16.3 (GND)
unnamed: C3.1, P1.2 (CAP)
unnamed: C4.1, P2.2 (CAP)
unnamed: C9.1, P5.2 (CAP)
unnamed: C10.1, P6.2 (CAP)
unnamed: C11.1, P7.2 (CAP)
unnamed: C12.1, P8.2 (CAP)
unnamed: C5.1, P3.2 (CAP)
unnamed: C6.1, P4.2 (CAP)
unnamed: C15.1, P9.2 (CAP)
unnamed: C16.1, P10.2 (CAP)
unnamed: C17.1, P11.2 (CAP)
unnamed: C18.1, P12.2 (CAP)
unnamed: C21.1, P13.2 (CAP)
unnamed: C22.1, P14.2 (CAP)
unnamed: C23.1, P15.2 (CAP)
unnamed: C24.1, P16.2 (CAP)
S0: IC1.10 (S0), JP2.4
S1: IC1.11 (S1), JP2.5
S2: IC1.14 (S2), JP2.6
S3: IC1.13 (S3), JP2.7
SCL: JP2.3, P1.8 (SCL), P2.8 (SCL), P3.8 (SCL), P4.8 (SCL), P5.8 (SCL), P6.8 (SCL), P7.8 (SCL), P8.8 (SCL), P9.8 (SCL), P10.8 (SCL), P11.8 (SCL), P12.8 (SCL), P13.8 (SCL), P14.8 (SCL), P15.8 (SCL), P16.8 (SCL), R6.1
SDA: IC1.1 (COMMON_INPUT/OUTPUT), JP2.2, R5.1
SDA1: IC1.9 (I0), P1.7 (SDA)
SDA2: IC1.8 (I1), P2.7 (SDA)
SDA3: IC1.7 (I2), P3.7 (SDA)
SDA4: IC1.6 (I3), P4.7 (SDA)
SDA5: IC1.5 (I4), P5.7 (SDA)
SDA6: IC1.4 (I5), P6.7 (SDA)
SDA7: IC1.3 (I6), P7.7 (SDA)
SDA8: IC1.2 (I7), P8.7 (SDA)
SDA9: IC1.23 (I8), P9.7 (SDA)
SDA10: IC1.22 (I9), P10.7 (SDA)
SDA11: IC1.21 (I10), P11.7 (SDA)
SDA12: IC1.20 (I11), P12.7 (SDA)
SDA13: IC1.19 (I12), P13.7 (SDA)
SDA14: IC1.18 (I13), P14.7 (SDA)
SDA15: IC1.17 (I14), P15.7 (SDA)
SDA16: IC1.16 (I15), P16.7 (SDA)
VDD: C1.1, C2.1, C7.1, C8.1, C13.1, C14.1, C19.1, C20.1, IC1.24 (VCC), JP2.1, P1.1 (VDD), P1.4 (VDDIO), P2.1 (VDD), P2.4 (VDDIO), P3.1 (VDD), P3.4 (VDDIO), P4.1 (VDD), P4.4 (VDDIO), P5.1 (VDD), P5.4 (VDDIO), P6.1 (VDD), P6.4 (VDDIO), P7.1 (VDD), P7.4 (VDDIO), P8.1 (VDD), P8.4 (VDDIO), P9.1 (VDD), P9.4 (VDDIO), P10.1 (VDD), P10.4 (VDDIO), P11.1 (VDD), P11.4 (VDDIO), P12.1 (VDD), P12.4 (VDDIO), P13.1 (VDD), P13.4 (VDDIO), P14.1 (VDD), P14.4 (VDDIO), P15.1 (VDD), P15.4 (VDDIO), P16.1 (VDD), P16.4 (VDDIO), R5.2, R6.2, R7.2

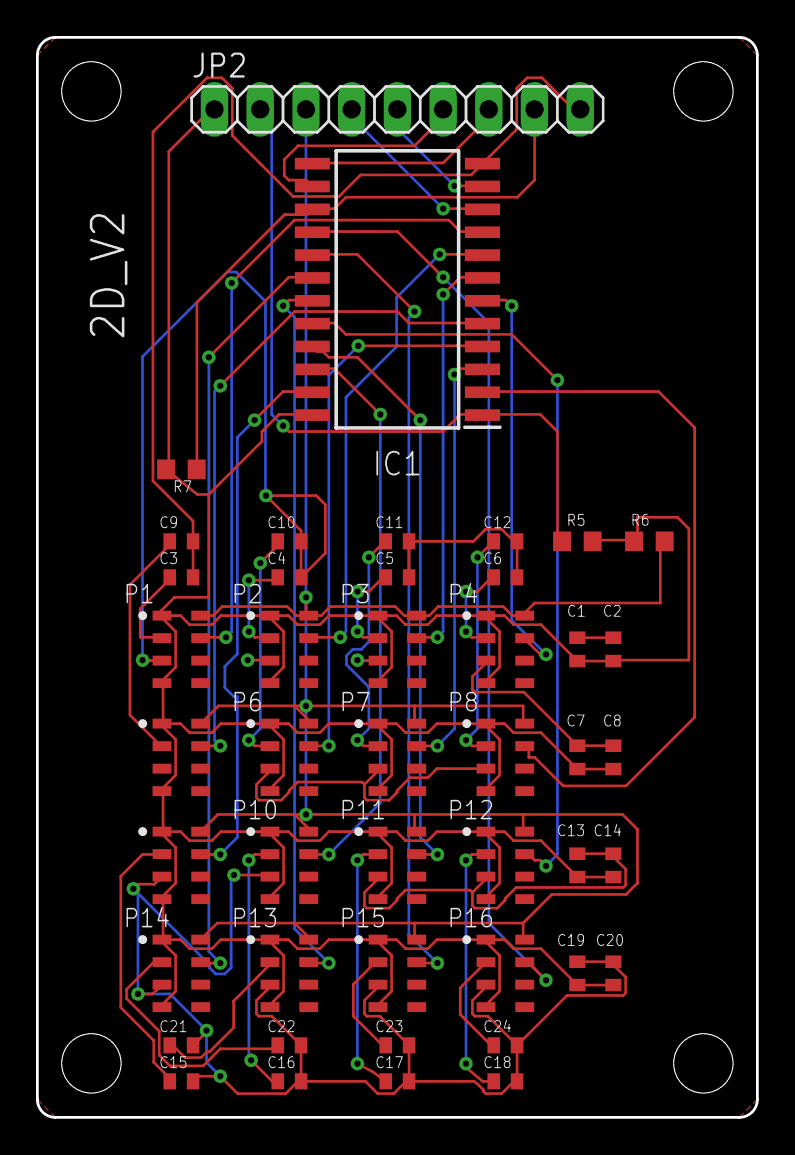
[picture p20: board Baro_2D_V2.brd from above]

Board: 2 copper layers, 40.0 x 60.0 mm, 45 parts (0 on the bottom side), 41 nets.

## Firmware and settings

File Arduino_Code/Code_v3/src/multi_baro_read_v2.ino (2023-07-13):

/*
MPL3115A2 Barometric Pressure Sensor Array
This sketch reads the pressure from 16 MPL3115A2 sensors

Hardware:
Arduino Uno
  -VCC = 3.3V
  -SDA = SDA
  -SCL = SCL
  -GND = GND
  -INT1 = not connected
  -INT2 = not connected
  -s0, s1, s2, s3 connected to digital pins 2, 3, 4, 5

Serial terminal at 9600bps
*/

#include <Wire.h> // for IIC communication
#include <Arduino.h>

// input pins for mux
int s0 = 2;
int s1 = 3;
int s2 = 4;
int s3 = 5;

// sensor number
// const int sensorNum = 16;
const int sensorNum = 16;
float pressureValues[sensorNum];
float tempValues[sensorNum];

//calibration values
// float coefficient[sensorNum] = {1, 1, 1, 1, 1 ,1 ,1 ,1 ,1 ,1 ,1 ,1 ,1 ,1 ,1 ,1};
// float coefficient[sensorNum] = {1, 1, 1, 1};
// time
int time_inter = 10; //time period btw switching
int t2 = millis();
int t1;

// position
int pos = 0;

int muxChannel[16][4] =
{
  {0, 0, 0, 0}, //channel 0
  {1, 0, 0, 0}, //channel 1
  {0, 1, 0, 0}, //channel 2
  {1, 1, 0, 0}, //channel 3
  {0, 0, 1, 0}, //channel 4
  {1, 0, 1, 0}, //channel 5
  {0, 1, 1, 0}, //channel 6
  {1, 1, 1, 0}, //channel 7
  {0, 0, 0, 1}, //channel 8
  {1, 0, 0, 1}, //channel 9
  {0, 1, 0, 1}, //channel 10
  {1, 1, 0, 1}, //channel 11
  {0, 0, 1, 1}, //channel 12
  {1, 0, 1, 1}, //channel 13
  {0, 1, 1, 1}, //channel 14
  {1, 1, 1, 1} //channel 15
}; 

#define STATUS     0x00
#define OUT_P_MSB  0x01
#define OUT_P_CSB  0x02
#define OUT_P_LSB  0x03
#define OUT_T_MSB  0x04
#define OUT_T_LSB  0x05
#define DR_STATUS  0x06
#define OUT_P_DELTA_MSB  0x07
#define OUT_P_DELTA_CSB  0x08
#define OUT_P_DELTA_LSB  0x09
#define OUT_T_DELTA_MSB  0x0A
#define OUT_T_DELTA_LSB  0x0B
#define WHO_AM_I   0x0C
#define F_STATUS   0x0D
#define F_DATA     0x0E
#define F_SETUP    0x0F
#define TIME_DLY   0x10
#define SYSMOD     0x11
#define INT_SOURCE 0x12
#define PT_DATA_CFG 0x13
#define BAR_IN_MSB 0x14
#define BAR_IN_LSB 0x15
#define P_TGT_MSB  0x16
#define P_TGT_LSB  0x17
#define T_TGT      0x18
#define P_WND_MSB  0x19
#define P_WND_LSB  0x1A
#define T_WND      0x1B
#define P_MIN_MSB  0x1C
#define P_MIN_CSB  0x1D
#define P_MIN_LSB  0x1E
#define T_MIN_MSB  0x1F
#define T_MIN_LSB  0x20
#define P_MAX_MSB  0x21
#define P_MAX_CSB  0x22
#define P_MAX_LSB  0x23
#define T_MAX_MSB  0x24
#define T_MAX_LSB  0x25
#define CTRL_REG1  0x26
#define CTRL_REG2  0x27
#define CTRL_REG3  0x28
#define CTRL_REG4  0x29
#define CTRL_REG5  0x2A
#define OFF_P      0x2B
#define OFF_T      0x2C
#define OFF_H      0x2D

#define MPL3115A2_ADDRESS 0x60 // 7-bit I2C address


void setup()
{
  char incomingByte;
  Wire.begin();        // join i2c bus
  Serial.begin(115200);  // start serial for output
  pinMode(s0, OUTPUT);
  pinMode(s1, OUTPUT);
  pinMode(s2, OUTPUT);
  pinMode(s3, OUTPUT);
  

  // Configure the sensor
  //setModeAltimeter(); // Measure altitude above sea level in meters
  for (int i = 0; i < sensorNum; i ++)
  {
    setChannel(i);
    if(IIC_Read(WHO_AM_I) == 196){
      Serial.print("Checking Sensor");Serial.println(i);
      // Serial.print("Sensor");Serial.print(i);
      // Serial.println(" MPL3115A2 online!");
    }
    else{
      Serial.print("Sensor");Serial.print(i);
      Serial.println(" No response - check connections");
    }
    if(IIC_Read(WHO_AM_I) == 196){
      Serial.print("Sensor");Serial.print(i);
      Serial.println(" MPL3115A2 online!");
    }
    else{
      Serial.print("Sensor");Serial.print(i);
      Serial.println(" No response - check connections");
    }
    setModeBarometer(); // Measure pressure in Pascals from 20 to 110 kPa
    setOversampleRate(4); // Set Oversample to the recommended 128
    enableEventFlags(); // Enable all three pressure and temp event flags
    delay(200);
  }
  // calibrateByCoefficient();
 

  // while no serial input; if available, save to variable
  if (Serial.available() > 0) {
    // read the incoming byte:
    incomingByte = Serial.read();
    // say what you got:
    Serial.print("I received: ");
    Serial.println(incomingByte, DEC);
  }

  // while (incomingByte != '1') {
  // }
  // Print out the header row
  Serial.println("Done");
  // Serial.println("Sensor_0 Sensor_1 Sensor_2 Sensor_3 x z t");
  

}

void loop()
{
  // Move position
  pos += 1; // Add code to move later
  // Read pressure
  // for (int i = 0; i < sensorNum; i ++)
  // {
  //   readPressureMux(i);
  //   // readTempMux(i);
  // }

  // // if serial input available, save to variable
  // for (int i = 0; i < sensorNum; i ++){
  //     Serial.print(pressureValues[i]);Serial.print(" ");
  // }Serial.println();

  for (int i = 4; i < 8; i ++)
  {
    readPressureMux(i);
    // readTempMux(i);
  }


  for (int i = 4; i < 8; i ++){
      Serial.print(pressureValues[i]);Serial.print(" ");
  }Serial.println();


}

//Returns the number of meters above sea level
float readAltitude()
{
  toggleOneShot(); //Toggle the OST bit causing the sensor to immediately take another reading

  //Wait for PDR bit, indicates we have new pressure data
  int counter = 0;
  while( (IIC_Read(STATUS) & (1<<1)) == 0)
  {
      if(++counter > 100) return(-999); //Error out
      delay(1);
  }
  
  // Read pressure registers
  Wire.beginTransmission(MPL3115A2_ADDRESS);
  Wire.write(OUT_P_MSB);  // Address of data to get
  Wire.endTransmission(false); // Send data to I2C dev with option for a repeated start. THIS IS NECESSARY and not supported before Arduino V1.0.1!
  Wire.requestFrom(MPL3115A2_ADDRESS, 3); // Request three bytes

  //Wait for data to become available
  counter = 0;
  while(Wire.available() < 3)
  {
    if(counter++ > 100) return(-999); //Error out
    delay(1);
  }

  byte msb, csb, lsb;
  msb = Wire.read();
  csb = Wire.read();
  lsb = Wire.read();

  toggleOneShot(); //Toggle the OST bit causing the sensor to immediately take another reading

  // The least significant bytes l_altitude and l_temp are 4-bit,
  // fractional values, so you must cast the calulation in (float),
  // shift the value over 4 spots to the right and divide by 16 (since 
  // there are 16 values in 4-bits). 
  float tempcsb = (lsb>>4)/16.0;

  float altitude = (float)( (msb << 8) | csb) + tempcsb;

  return(altitude);
}

//Returns the number of feet above sea level
float readAltitudeFt()
{
  return(readAltitude() * 3.28084);
}

//Reads the current pressure in Pa
//Unit must be set in barometric pressure mode
float readPressure()
{
  toggleOneShot(); //Toggle the OST bit causing the sensor to immediately take another reading

  //Wait for PDR bit, indicates we have new pressure data
  int counter = 0;
  while( (IIC_Read(STATUS) & (1<<2)) == 0)
  {
      if(++counter > 100) return(-999); //Error out
      delay(1);
  }

  // Read pressure registers
  Wire.beginTransmission(MPL3115A2_ADDRESS);
  Wire.write(OUT_P_MSB);  // Address of data to get
  Wire.endTransmission(false); // Send data to I2C dev with option for a repeated start. THIS IS NECESSARY and not supported before Arduino V1.0.1!
  Wire.requestFrom(MPL3115A2_ADDRESS, 3); // Request three bytes

  //Wait for data to become available
  counter = 0;
  while(Wire.available() < 3)
  {
    if(counter++ > 100) return(-999); //Error out
    delay(1);
  }

  byte msb, csb, lsb;
  msb = Wire.read();
  csb = Wire.read();
  lsb = Wire.read();

  toggleOneShot(); //Toggle the OST bit causing the sensor to immediately take another reading

  // Pressure comes back as a left shifted 20 bit number
  long pressure_whole = (long)msb<<16 | (long)csb<<8 | (long)lsb;
  pressure_whole >>= 6; //Pressure is an 18 bit number with 2 bits of decimal. Get rid of decimal portion.

  lsb &= 0b00110000; //Bits 5/4 represent the fractional component
  lsb >>= 4; //Get it right aligned
  float pressure_decimal = (float)lsb/4.0; //Turn it into fraction

  float pressure = (float)pressure_whole + pressure_decimal;

  return(pressure);
}

float readTemp()
{
  toggleOneShot(); //Toggle the OST bit causing the sensor to immediately take another reading

  //Wait for TDR bit, indicates we have new temp data
  int counter = 0;
  while( (IIC_Read(STATUS) & (1<<1)) == 0)
  {
      if(++counter > 100) return(-999); //Error out
      delay(1);
  }
  
  // Read temperature registers
  Wire.beginTransmission(MPL3115A2_ADDRESS);
  Wire.write(OUT_T_MSB);  // Address of data to get
  Wire.endTransmission(false); // Send data to I2C dev with option for a repeated start. THIS IS NECESSARY and not supported before Arduino V1.0.1!
  Wire.requestFrom(MPL3115A2_ADDRESS, 2); // Request two bytes

  //Wait for data to become available
  counter = 0;
  while(Wire.available() < 2)
  {
    if(++counter > 100) return(-999); //Error out
    delay(1);
  }

  byte msb, lsb;
  msb = Wire.read();
  lsb = Wire.read();
  
  // The least significant bytes l_altitude and l_temp are 4-bit,
  // fractional values, so you must cast the calulation in (float),
  // shift the value over 4 spots to the right and divide by 16 (since 
  // there are 16 values in 4-bits). 
  float templsb = (lsb>>4)/16.0; //temp, fraction of a degree

  float temperature = (float)(msb + templsb);

  return(temperature);
}

//Give me temperature in fahrenheit!
float readTempF()
{
  return((readTemp() * 9.0)/ 5.0 + 32.0); // Convert celsius to fahrenheit
}

//Sets the mode to Barometer
//CTRL_REG1, ALT bit
void setModeBarometer()
{
  byte tempSetting = IIC_Read(CTRL_REG1); //Read current settings
  tempSetting &= ~(1<<7); //Clear ALT bit
  IIC_Write(CTRL_REG1, tempSetting);
}

//Sets the mode to Altimeter
//CTRL_REG1, ALT bit
void setModeAltimeter()
{
  byte tempSetting = IIC_Read(CTRL_REG1); //Read current settings
  tempSetting |= (1<<7); //Set ALT bit
  IIC_Write(CTRL_REG1, tempSetting);
}

//Puts the sensor in standby mode
//This is needed so that we can modify the major control registers
void setModeStandby()
{
  byte tempSetting = IIC_Read(CTRL_REG1); //Read current settings
  tempSetting &= ~(1<<0); //Clear SBYB bit for Standby mode
  IIC_Write(CTRL_REG1, tempSetting);
}

//Puts the sensor in active mode
//This is needed so that we can modify the major control registers
void setModeActive()
{
  byte tempSetting = IIC_Read(CTRL_REG1); //Read current settings
  tempSetting |= (1<<0); //Set SBYB bit for Active mode
  IIC_Write(CTRL_REG1, tempSetting);
}

//Setup FIFO mode to one of three modes. See page 26, table 31
//From user jr4284
void setFIFOMode(byte f_Mode)
{
  if (f_Mode > 3) f_Mode = 3; // FIFO value cannot exceed 3.
  f_Mode <<= 6; // Shift FIFO byte left 6 to put it in bits 6, 7.

  byte tempSetting = IIC_Read(F_SETUP); //Read current settings
  tempSetting &= ~(3<<6); // clear bits 6, 7
  tempSetting |= f_Mode; //Mask in new FIFO bits
  IIC_Write(F_SETUP, tempSetting);
}

//Call with a rate from 0 to 7. See page 33 for table of ratios.
//Sets the over sample rate. Datasheet calls for 128 but you can set it 
//from 1 to 128 samples. The higher the oversample rate the greater
//the time between data samples.
void setOversampleRate(byte sampleRate)
{
  if(sampleRate > 7) sampleRate = 7; //OS cannot be larger than 0b.0111
  sampleRate <<= 3; //Align it for the CTRL_REG1 register

  byte tempSetting = IIC_Read(CTRL_REG1); //Read current settings
  tempSetting &= 0b11000111; //Clear out old OS bits
  tempSetting |= sampleRate; //Mask in new OS bits
  IIC_Write(CTRL_REG1, tempSetting);
}

//Clears then sets the OST bit which causes the sensor to immediately take another reading
//Needed to sample faster than 1Hz
void toggleOneShot(void)
{
  byte tempSetting = IIC_Read(CTRL_REG1); //Read current settings
  tempSetting &= ~(1<<1); //Clear OST bit
  IIC_Write(CTRL_REG1, tempSetting);

  tempSetting = IIC_Read(CTRL_REG1); //Read current settings to be safe
  tempSetting |= (1<<1); //Set OST bit
  IIC_Write(CTRL_REG1, tempSetting);
}

//Enables the pressure and temp measurement event flags so that we can
//test against them. This is recommended in datasheet during setup.
void enableEventFlags()
{
  IIC_Write(PT_DATA_CFG, 0x07); // Enable all three pressure and temp event flags 
}

// These are the two I2C functions in this sketch.
byte IIC_Read(byte regAddr)
{
  // This function reads one byte over IIC
  Wire.beginTransmission(MPL3115A2_ADDRESS);
  Wire.write(regAddr);  // Address of CTRL_REG1
  Wire.endTransmission(false); // Send data to I2C dev with option for a repeated start. THIS IS NECESSARY and not supported before Arduino V1.0.1!
  Wire.requestFrom(MPL3115A2_ADDRESS, 1); // Request the data...
  return Wire.read();
}

void IIC_Write(byte regAddr, byte value)
{
  // This function writes one byto over IIC
  Wire.beginTransmission(MPL3115A2_ADDRESS);
  Wire.write(regAddr);
  Wire.write(value);
  Wire.endTransmission(true);
}

void setChannel(int channel)
{
  int controlPin[] = {s0, s1, s2, s3};
  // loop through the 4 sig
  for (int i = 0; i < 4; i ++)
  {
    digitalWrite(controlPin[i], muxChannel[channel][i]);
  }
  return 0;
}

// calibration by coefficient
void calibrateByCoefficient()
{
  float sumSensor[sensorNum] = {0};
  float sum = 0;
  float avg = 0;
  Serial.println("Calibrating...");
  for (int i = 0; i < sensorNum; i ++)
  {
    readPressureMux(i);
    Serial.print("sensor "); Serial.print(i); Serial.print("value 1"); Serial.print(": "); Serial.println(pressureValues[i]);
    sumSensor[i] += pressureValues[i];
    readPressureMux(i);
    Serial.print("sensor "); Serial.print(i); Serial.print("value 2"); Serial.print(": "); Serial.println(pressureValues[i]);
    sumSensor[i] += pressureValues[i];
    readPressureMux(i);
    Serial.print("sensor "); Serial.print(i); Serial.print("value 3"); Serial.print(": "); Serial.println(pressureValues[i]);
    sumSensor[i] += pressureValues[i];
    sumSensor[i] = sumSensor[i] / 3;
    sum += sumSensor[i];
  }
  avg = sum / sensorNum;
  Serial.println(avg);
  delay(300);

  // calculate coefficient
  // for (int i = 0; i < sensorNum; i ++)
  // {
  //   coefficient[i] = sumSensor[i];
  //   Serial.print("coefficient["); Serial.print(i); Serial.print("]: ");  
  //   Serial.println(coefficient[i]);
  // }
  // pressure after calibration
  for (int i = 0; i < sensorNum; i ++)
  {
    pressureValues[i] = pressureValues[i];
    Serial.print("pressureValues["); Serial.print(i); Serial.print("]: ");  
    Serial.println(pressureValues[i]);
  }

  Serial.println("Calibration done.");
}


void readPressureMux(int channel)
{
  setChannel(channel);
  // Serial.print("Sensor "); Serial.println(channel);
  pressureValues[channel] = readPressure();
  // Serial.print(" Pressure(Pa):");
  // Serial.println(pressureValues[channel], 2);

  // t1 = millis();
  // Serial.print(" time diff:");
  // Serial.print(t1 - t2);
  // Serial.println();
  // t2 = t1;
  delay(time_inter);
}

void readTempMux(int channel)
{
  setChannel(channel);
  // Serial.print("Sensor "); Serial.println(channel);
  tempValues[channel] = readTemp();
  // Serial.print(" Temperature(C):");
  // Serial.println(tempValues[channel], 2);

  t1 = millis();
  // Serial.print(" time diff:");
  // Serial.print(t1 - t2);
  // Serial.println();
  t2 = t1;
  delay(time_inter);
}

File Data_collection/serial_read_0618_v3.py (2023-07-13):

# install ：pip3 install pyserial   //python3
import serial
import serial.tools.list_ports
import time
import csv
import datetime
import io
import os

# Initialize serial ports

# Testing Rig
arduino = serial.Serial('COM4', 115200, timeout=0.01)
arduino_io = io.TextIOWrapper(io.BufferedRWPair(arduino, arduino,1))
arduino_io._CHUNK_SIZE = 1
commandList = []

# Sensor
com = serial.Serial('COM5', 115200, timeout=0.01)
sensorFlag = 0

ticks = time.time()
timeFlag = 0

com_rx_buf = ''              # Receive buffer
com_tx_buf = ''              # Transmit buffer
COMM = serial.Serial()      # Define serial object s
port_list: list              # List of available serial ports
port_select: list            # Selected serial port

posX = 0
posZ = 0

tableHead = ['Sensor_0', 'Sensor_1', 'Sensor_2', 'Sensor_3', 'x', 'z', 'time']
# tableHead = ['Sensor_0', 'Sensor_1', 'Sensor_2', 'Sensor3', 'Sensor_4', 'Sensor_5', 'Sensor_6', 'Sensor7', 'sensor_8', 'Sensor_9', 'Sensor_10', 'Sensor_11', 'Sensor_12', 'Sensor_13', 'Sensor_14', 'Sensor_15', 'x', 'z', 'time']
def readSerial():
    output = arduino_io.read()
    # if (output != ''):
        # print(output)
    return output

def readSerialLine():
    output = arduino_io.readline()
    if (output != ''):
        print(output)
    return output

def writeSerial(x):
    # arduino_io.write(x+'\n')
    arduino_io.write(x+'\r\n')

    arduino_io.flush()

def move_mm(x):
    if (x > 0):
        # writeSerial('mm+' + str(x))
        commandList.append('mm+' + str(x))
    else:
        #  writeSerial('mm' + str(x))
         commandList.append('mm' + str(x))

    # waitForCompletion()

def zmove_mm(x):
    if (x > 0):
        commandList.append('zmm+' + str(x))
        # writeSerial('zmm+' + str(x))
    else:
        commandList.append('zmm' + str(x))
        #  writeSerial('zmm' + str(x))

    # waitForCompletion()

def home():
    commandList.append('home')
    # writeSerial('home')
    # waitForCompletion()


def zhome():
    commandList.append('zhome')
    # writeSerial('zhome')
    # waitForCompletion()

# def waitForCompletion():
#     while(readSerialLine() != 'Done\n'):
#         pass

def runNext():
    writeSerial(commandList[0])
    commandList.pop(0)


if __name__ == '__main__':

    dir_path = './tip1'
    if not os.path.exists(dir_path):
        os.makedirs(dir_path)

    stop = False
    trial = 0

    Pattern = input('Pattern:')
    current_datetime = datetime.datetime.now().strftime('%Y%m%d_%H%M%S')  # Get current date and time as a string
    file_name = os.path.join(dir_path, f"{Pattern}_{current_datetime}.csv")

    time.sleep(6)
    print('--')
    readSerial()
    time.sleep(1)

    #Write sequence into command list:
    zhome()
    home()
    time.sleep(1)
    

    for i in range(18):
        z_distance = 4
        zmove_mm(z_distance)
        zmove_mm(-z_distance)
        move_mm(-1)

    # for i in range(7):
    #     # z increament with 0.1mm from 0 to 3.6mm
    #     z_distance = 0.2
    #     steps = 11
    #     zPre = 1.8

    #     zmove_mm(zPre)
    #     for j in range(steps):
    #         zmove_mm(z_distance)
    #     zmove_mm(-z_distance*steps-zPre)
    #     move_mm(-1)

    print(commandList)
    runNext()


    while not stop:
        try:
            while True:
                serialData = readSerialLine()
                # print(arduino.in_waiting)
                if (serialData != ''):
                    if (serialData == 'Done\n'):
                        runNext()
                    if (serialData[0] == 'x'):
                        posX = int(serialData[1:])
                    if (serialData[0] == 'z' and serialData[1] == 'p'):
                        posZ = int(serialData[2:])
                # print(com.in_waiting)



                if (com.in_waiting > 0):
                    line = com.readline()
                    
                    # checking if the sensor is working
                    if (line == b'Done\r\n'):
                        sensorFlag = 1
                        with open(file_name, 'a', newline='') as csvfile:
                            csv_writer = csv.writer(csvfile)
                            csv_writer.writerow(tableHead)  # Write the data as a row in the CSV file
                    
                    elif (sensorFlag == 1):
                        line = line.decode().strip()
                        data = line.split(' ')  # Split the line by space
                        data.append(str(posX))
                        data.append(str(posZ))
                        if timeFlag == 0:
                            ticks = time.time()
                            cTime = 0
                            timeFlag = 1
                        cTime = time.time() - ticks
                        data.append(str(cTime))
                        with open(file_name, 'a', newline='') as csvfile:
                            csv_writer = csv.writer(csvfile)
                            csv_writer.writerow(data)  # Write the data as a row in the CSV file
        except:
            print(f'File saved to {file_name}')
            exit(0)
